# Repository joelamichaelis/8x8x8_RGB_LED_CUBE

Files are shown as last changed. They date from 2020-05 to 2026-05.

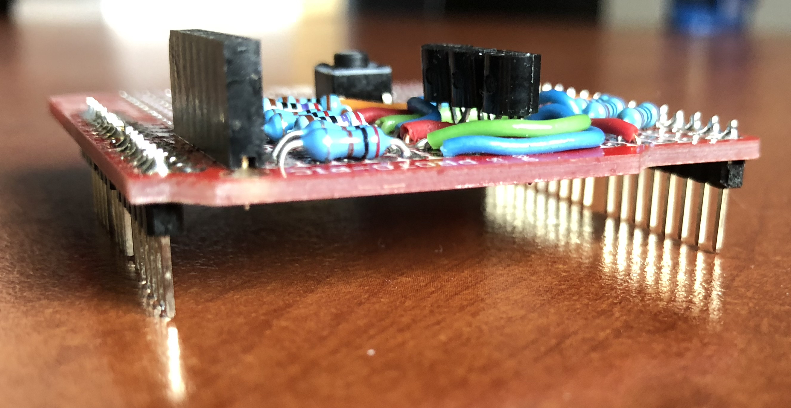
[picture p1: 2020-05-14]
Documents/Steve Manley Resources/Images/LED Tester.jpg

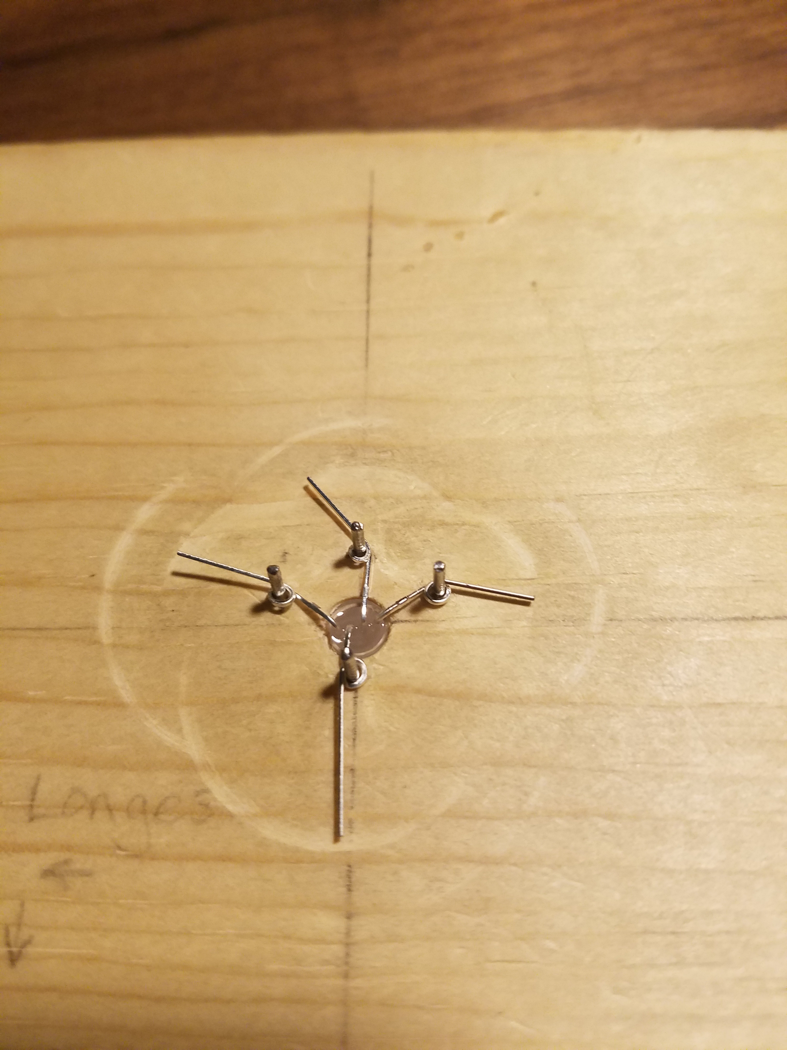
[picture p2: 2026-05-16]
Project Photos/Phase 1 Cube Build/01 LED Bending/20180319_184943.jpg

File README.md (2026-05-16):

#8x8x8 RGB LED Cube Project
2026: cleaning up the repo a bit and making public primarily for archival purposes.
This repo contains detail on the 8x8x8 RGB LED cube project I worked on in 2 phases between 2018 & 2021 primarily.

#Phase 1:
A classmate and I built the cube back in 2018 for our senior design class.
This encompassed:
1. building the physical cube itself.
2. building prototype grade electronics wired to the cube and arduino.
3. Programming the arduino to do basic animations on the cube.
This is all we had time to do.

#Pase 2:
I kept the RGB cube and after graduating wanted to keep working on the project.
I designed, ordered, and built a motherboard pcb which eliminates the need for a messy jumble of wires under the led cube and instead plugs in directly.
It is powered by a 5V 5-10A power supply, drives the LED cube with a STM32F103 Blue Pill, has a display LCD, capacitive touch menu naviagation system, and more.

#Current State:
I took an indefinite hiatus just short of having something visually impressive I can easily power on and showcase different animations on.
Designing the motherboard specifically was a great learning experience. This is the first serious PCBA schematic + layout I designed myself.
Same goes for the STM32 firmware piece. Prior to this I was still using primarily arduino.
If I were to continue the project in the future, I would prioritize first cleaning up the firmware repo because it is a mess.

Also, check out companion repo: https://github.com/joelamichaelis/Eight-Cubed-RGB.
It appears that I later made that repo to try and migrate away from the messy firmware files here. Not sure how well that helped now having 2 repos.

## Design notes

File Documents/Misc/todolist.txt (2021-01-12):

---------------------HW Considerations------------------------------------------------------

Drill holes in DC barrel jack footprint so it locks in place
Reconsider via spacings with consideration for CAF
Expandable modular GPIO interface feasibility
Is some sort of ext flash necessary?
Consider possibility of power switches for VLCD, ...

---------------------FW chicken scratching----------------------------------------------------

// the mask & color ar
fade (in or out?)
dissolve (in or out?) (ascending, descending, random?)
fade(dissolve) //

void raindrops (int initialFillDensity)
initial frame: The topmost layer frame is initialized to a certain "fill density"
subsequent frames: 
- shift down any active column by one
- count how many columns vanished. that's how many random columns to init next frame.

transition_punch	// already implemented 
transition_fade		// already implemented but need to clean up
transition_dissolve	// yet to be implemented. A combination of punch & fade

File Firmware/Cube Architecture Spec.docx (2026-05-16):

2026 note: don’t take this as source of truth. Looks like I was brainstorming stuff here. Some of this is true though.

Operational Modes:

- Video Mode
  - Cube runs through pre-scripted pattern sequences
- Interactive Mode
  - Cube takes inputs from peripherals to generate patterns
- Debug Mode
  - Allows user to toggle LEDs on and off manually for HW testing

Abstraction Layers:

Highest Level: Applicatation

Mid level:

- Controls the HW stuff
- LED mapping

Lowest Level:

Board config/initialization stuff

Application Layer

- Sequencer Layer slices 3d images into layers and sequences them
  - Layer Layer TLC set, clear, SPI convert, …
    - Chip Support Layer Board config stuff

Main.c:

- menu_system.c
  - mpr121.c
  - lcd_20x4_i2c.c
- animations.c
  - tlc5940.c
  - bool_mask.c
  - frame.c
  - lyr_frame.c

menu_system.c

Purpose:

synchronizes capacitive touch mpr121 inputs with the lcd to create a “menu system”

includes:

mpr121.c

lcd20x4_i2c.c

functions:

Purpose

char Menu_Read_Keypad();

char Menu_Read_Wheel();

Menu_TypeDef Menu_Scroll_Up(Menu_TypeDef tempMenu);

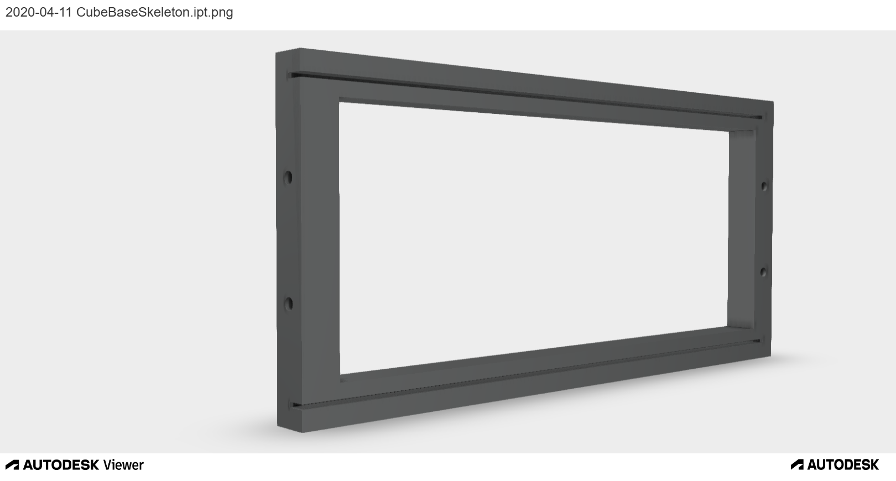
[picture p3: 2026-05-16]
Project Photos/Phase 2 Photos/Mechanical Renders/2020-04-11 CubeBaseSkeleton.ipt_REAR.png

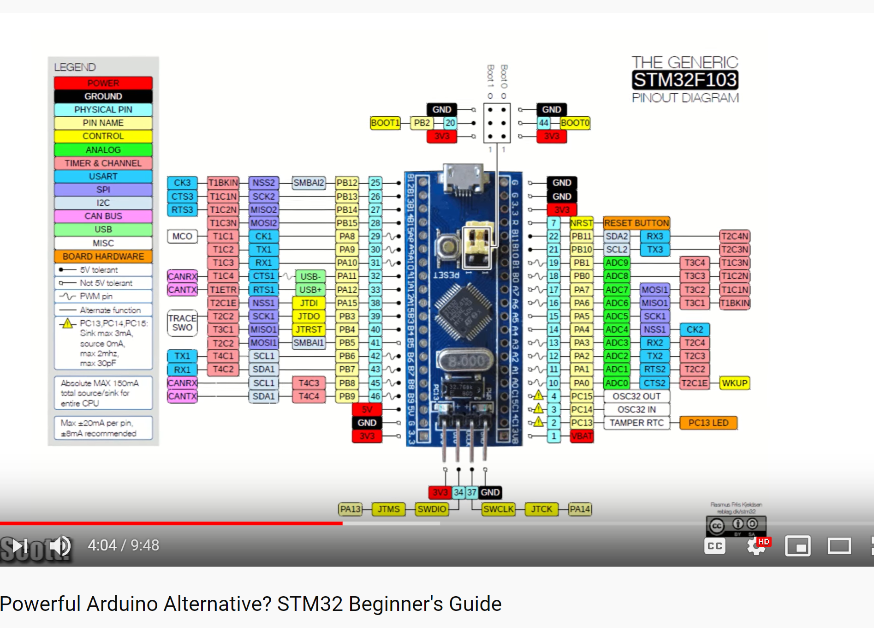
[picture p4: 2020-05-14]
Datasheets/Microprocessor/STM32F103 Generic Pinout.PNG

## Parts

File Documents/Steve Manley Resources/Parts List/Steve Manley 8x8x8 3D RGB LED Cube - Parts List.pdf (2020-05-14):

# Steve%Manley%– 8x8x8%3D%RGB%LED%Cube%– Parts%List

Item | Description | Quantity / Cube | Cost | Where Purchased | Additional Information
RGB LED | 5mm Diffused Common Anode RGB LED | 512 | £34.46 / 1000 LEDs | eBay: http://www.ebay.co.uk/itm/1000pcs-5mm-Round-top-Diffused-Multicolor-4-pins-Common-Anode-RGB-LED-light-/151281086209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: GB:1123
| Forward Voltage(V) If=20mA | Dominant wavelength(mm)K If=20mA | LuMen(LM) If=20mA | Reverse current(uA) Vr=5V | Power Angle (deg)
Min | Typ | Min | Typ | Min | Typ | Max
Red | 2.1 | 2.4 | 620 | 630 | 3000 | 4000 | 10 | 20-25
Green | 3.0 | 3.4 | 520 | 530 | 6000 | 8000 | 10 | 20-25
Blue | 3.0 | 3.4 | 460 | 465 | 4000 | 5000 | 10 | 20-25
Tinned Copper Wire | 20 SWG (or 20 AWG) 500g Real | 1 | £13.55 / Real | eBay: http://www.ebay.co.uk/itm/20-SWG-Tinned-Copper-Wire-500g-CB903-/160533739486?ssPageName=ADME:L:OU: GB:3160
Parameter | Value
Conductor Area CSA | 0.66mm²
External Diameter | 0.914mm
Conductor Make-up | 1/0.914mm
Current Rating | 33A
SWG Number | 20
Length | 86m
Base PCB | Interface for the Cube and Control Circuits Custom sized board with white solder mask. | 1 | £276 / 5 Boards | Proto-Pic: http://proto-pic.co.uk/large-pcb-prototype-manufacturing-service-250mm-x-250mm/ | Board Dimension are: 100mm x 100mm (max) for standard PCB (quantity 10) 250mm x 250mm (max) for larger PCB (quantity 5)
Parameter | Value
Material | FR-4
Board Dimension (min) | 10mm X10mm
Outline Dimension Accuracy | ± 0.2mm
Board Thickness | 1.6mm
Board Thickness Tolerance | ± 10%
Dielectric Separation thickness | 0.075mm--5.00mm
Conductor Width (min) | 0.15mm( Recommend>8mil )
Conductor Space (min) | 0.15mm( Recommend>8mil)
Outer Conductor thickness | 35um (1 Oz Copper)
Inner Conductor thickness | 17um--100um
Copper to Edge | 0.25mm,0.5mm
Plated Component,Plated via Diameter(Mechanical) | 0.3mm--6.30mm
Plated Hole Diameter Tolerance(Mechanical) | 0.08mm
Unplated Hole Diameter Tolerance | 0.05mm
Hole Space(min) | 0.25mm
Hole to Edge | 0.4mm
Annular Ring(min) | 0.15mm
Aspect Ratio | 8:01
Solder Resist Type | Photosensitive ink
Solder Resist Color | Black ,Green, White, Blue ,Yellow, Red
Solder Resist Clearance | 0.1mm
Solder Resist Coverage | 0.1mm
Plug Hole Diameter | 0.3mm--0.65mm
Selective Finish | HASL, ENIG
Silkscreen line width (mim) | 6mil
8 Pin Male SM Header | 8 Pin Mail surface Mount Header (mounts onto Base PCB) | 24 | £0.29 each | Proto-Pic: http://proto-pic.co.uk/header-8-pin-male-smd-0-1/ | Pin spacing is 0.1 inch See Datasheet on vendor website
8 Pin Female Header | 8 Pin Female Stackable Header (mounts onto Shift Register Boards) | 24 | £0.35 each | Proto-Pic: http://proto-pic.co.uk/8-pin-stackable-header-for-arduino/ | Pin spacing is 0.1 inch See Datasheet on vendor website
4 Way Molex Housing | Molex 22-01-2045 Crimp Housing, 2.54MM, 4 way | 17 | £2.10 / pack 10 | Farnell: http://uk.farnell.com/molex/22-01-2045/crimp-housing-2-54mm-4way/dp/143128?CMP=i-bf9f-00001000 | Pin spacing is 0.1 inch See Datasheet on vendor website
4 Pin Molex Header | Molex 22-05-7048 Connector, Header, THT, RA, 2.54MM, 4 way | 17 | £2.84 / pack 5 | Farnell: http://uk.farnell.com/molex/22-05-7048/connector-header-tht-ra-2-54mm/dp/9731628?ost=9731628 | Pin spacing is 0.1 inch See Datasheet on vendor website
Shift Register Board | Drives the LED Cathodes

## Standard sized board

## 4 £78 / 10 Boards

## Proto-Pic:

https://proto-pic.co.uk/pcb-prototypemanufacturing-service-10-boards/

Anode Driver Board | Multiplexes the Anodes

## Custom sized board

## 1 £100 / 5 Boards

## Proto-Pic:

http://proto-pic.co.uk/large-pcb-prototypemanufacturing-service-250mm-x-250mm/

Item | Description | Quantity / Cube | Cost | Where Purchased | Additional Information
Molex Contact Pin | Molex 08-50-0032 Contact, Socket, 30-22AWG, Crimp | 60 | £7.38 / pack 100 | Farnell: http://uk.farnell.com/molex/08-50-0032/contact-socket-30-22awg-crimp/dp/2424111?MER=baynote-2424111-pr | See Datasheet on vendor website
Pluggable Terminal Block 3 Way 5MM | Imo Precision Controls 20.130M/3 Terminal Block, Pluggable, 3POS, 5MM,14AWG | 5 | £1.42 / pack 2 | Farnell: http://uk.farnell.com/imo-precision-controls/20-130m-3/terminal-block-pluggable-3pos/dp/9632590 | See Datasheet on vendor website
Header Through Hole 5MM | Imo Precision Controls 20.130M/PS Connector, Header, THT, 5MM, 24WAY | 15 | £1.09 / strip 24 | Farnell: http://uk.farnell.com/imo-precision-controls/20-130m-ps/connector-header-tht-5mm-24way/dp/9632620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 | See Datasheet on vendor website
Shift Register TLC5916IN | Texas Instruments TLC5916IN Constant Current, LED Driver, 8Bit, PDIP16 | 24 | £1.53 each | Farnell: http://uk.farnell.com/texas-instruments/tlc5916in/ic-led-driver-8ch-pdip16/dp/1647814?CMP=i-bf9f-00001000 | See Full Datasheet on vendor website
Shift Register SN74HC595N | Texas Instruments SN74HC595N Shift Register, 8BIT, DIP16 | 1 | £0.54 each | Farnell: http://uk.farnell.com/texas-instruments/sn74hc595n/shift-register-8bit-74hc595-dip16/dp/9591664 | See Full Datasheet on vendor website
Hex Buffer | Texas Instruments CD74HC4050E Logic, Non-inverting, Hex, 1 Input, 16DIP | 1 | £0.48 each | Farnell: http://uk.farnell.com/texas-instruments/cd74hc4050e/logic-non-inv-hex-1input-16dip/dp/1739945?ost=1739945 | See Full Datasheet on vendor website
P-Channel Power MOSFET 19A | International Semiconductors AUIRF9Z34N MOSFET, P CH, 55V, 19A, TO-220AB | 8 | £0.94 each | Farnell: http://uk.farnell.com/international-rectifier/auirf9z34n/mosfet-p-ch-55v-19a-to-220ab/dp/2062068?ost=2062068 | See Full Datasheet on vendor website
Rectifier Diode 1A | Vishay General Semiconductor 1N4004 E3/54 Rectifier, Standard, 1A, 400V, DO-204AL | 1 | £0.95 each | Farnell: http://uk.farnell.com/vishay-general-semiconductor/1n4004-e3-54/rectifier-standard-1a-400v-do/dp/2335181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 | See Datasheet on vendor website
Capacitor 100nF 50V | Kemet C320C104K5R5TA CAP, MLCC, X7R, 100NF, 50V, RAD | 34 | £1.02 / pack 10 | Farnell: http://uk.farnell.com/kemet/c320c104k5r5ta/ca p-mlcc-x7r-100nf-50v-rad/dp/1457655?ost=1457655 | See Datasheet on vendor website

Item | Description | Quantity / Cube | Cost | Where Purchased | Additional Information
Capacitor 100uF 25V Electrolytic | Rubycon 25YXF100MEFC6.3X11 CAP, ALU ELEC, 100UF, 25V, RAD | 6 | £0.79 / pack 5 | Farnell: http://uk.farnell.com/rubycon/25yxf100mefc6-3x11/cap-alu-elec-100uf-25v-rad/dp/1144620?ost=1144620 | See Datasheet on vendor website
Resistor 100R 0.25W | Multicomp MF25 100R Resistor, 0.25W, 1% | 8 | £1.35 / pack 50 | Farnell: http://uk.farnell.com/multicomp/mf25-100r/resistor-100r-0-25w-1/dp/9341099?ost=9341099 | See Datasheet on vendor website
Resistor 100R 0.25W | Multicomp MF12 1K Resistor, 0.125W, 1% | 32 | £0.29 / pack 10 | Farnell: http://uk.farnell.com/multicomp/mf12-1k/resistor-1k-0-125w-1/dp/9342400 | See Datasheet on vendor website
6V 3.3A Power Supply | Ideal Power Supply 6V 5206-20S06-V-3A PSU, 6V, 3.3A, Earthed Output | 1 | £15.78 each | Farnell: http://uk.farnell.com/ideal-power/5206-20s06-v-3a/psu-6v-3-3a-earthed-output/dp/2112015?ost=2112015 | See Datasheet on vendor website

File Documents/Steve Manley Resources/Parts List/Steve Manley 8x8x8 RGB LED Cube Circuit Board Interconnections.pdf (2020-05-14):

Steve Manley 8x8x8 RGB LED Cube - Circuit Board Interconnections

Anode Driver Board | Arduino Uno
JP1 - DATA IN | Pin 11
JP1 - CLK IN | Pin 13
JP1 - LE IN | Pin 3
JP1 - ~OE IN | Pin 2
JP2 - GND | GND (next to Pin 13)
X4 - 6V IN | DC Power Jack +V
X5 - GND | DC Power Jack 0V
Anode Driver Board JP3 | Shift Register Board 1 JP1
Pin 1 | Pin 1
Pin 2 | Pin 2
Pin 3 | Pin 3
Pin 4 | Pin 4
Anode Driver Board JP4 | Shift Register Board 1 JP2
GND | Pin 4
Anode Driver Board JP5 | Shift Register Board 3 JP1
Pin 2 | Pin 2
Pin 3 | Pin 3
Pin 4 | Pin 4
Anode Driver Board | Base Board
X1 – A0 | Anode 0
X1 – A1 | Anode 1
X1 – A2 | Anode 2
X2 – A3 | Anode 3
X2 – A4 | Anode 4
X3 – A5 | Anode 5
X3 – A6 | Anode 6
X3 – A7 | Anode 7
Anode Driver Board | External 6V Power Supply
X4 - 6V IN | +6 Volts
X5 - GND | 0 Volts

Shift Register Board 1 JP3 | Shift Register Board 2 JP1
Pin 1 | Pin 1
Pin 2 | Pin 2
Pin 3 | Pin 3
Pin 4 | Pin 4
Shift Register Board 2 JP3 | Shift Register Board 3 JP1
Pin 1 | Pin 1
Shift Register Board 3 JP3 | Shift Register Board 4 JP1
Pin 1 | Pin 1
Pin 2 | Pin 2
Pin 3 | Pin 3
Pin 4 | Pin 4

Shift Register Board 4 JP3
Pin 1 – Not Connected
Pin 2 – Not Connected
Pin 3 – Not Connected
Pin 4 – Not Connected
All Shift Register Boards JP2 | Anode Driver Board
Pin 1 – Not Connected
Pin 2 | X4 - 5V OUT
Pin 3 | X5 - GND

All Shift Register Boards JP2
Board 1 Pin 4 | Board 2 Pin 4
Board 2 Pin 4 | Board 3 Pin 4
Board 3 Pin 4 | Board 4 Pin 4

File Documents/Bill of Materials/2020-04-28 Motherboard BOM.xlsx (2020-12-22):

 |  | Distributor | In Stock? | QTY | Unit Cost ($) | Extended Cost ($) | URL
 | BC847CW,115 | LCSC | Y | 15 | 0.02 | 0.3 | https://lcsc.com/product-detail/Transistors-NPN-PNP_Nexperia-BC847CW-115_C75567.html | Q3, Q4, Q7, Q8, Q11, Q12, Q15, Q16, Q18, Q21, Q22, Q25, Q26, Q29, Q30
 | BC857 | LCSC | Y | 7 | 0.013017 | 0.091119 | https://lcsc.com/product-detail/Transistors-NPN-PNP_ST-Semtech-BC857_C148244.html | Q17, Q19, Q20, Q23, Q24, Q27, Q28
 | BSS138LT1G | Digikey | Y | 2 | 0.25 | 0.5 | https://www.digikey.com/product-detail/en/on-semiconductor/BSS138LT1G/BSS138LT1GOSCT-ND/917858 | Q31, Q32
 | IRF9540 | Digikey | Y | 8 | 2.32 | 18.56 | https://www.digikey.com/product-detail/en/vishay-siliconix/IRF9540STRLPBF/IRF9540STRLPBFCT-ND/3305342 | Q1, Q2, Q5, Q6, Q9, Q10, Q13, Q14
 | LED-0603-001 | LCSC | Y | 2 | 0.066219 | 0.132438 | https://lcsc.com/product-detail/Infrared-IR-LEDs_IR19-21C-TR8-AQL_C142316.html | DS1, DS2
 | RES-0402-75K | LCSC | Y | 2 | 0.000904 | 0.001808 | https://lcsc.com/product-detail/Chip-Resistor-Surface-Mount_UNI-ROYAL-Uniroyal-Elec-0402WGF7502TCE_C25798.html | R86, R89
 | RES-0402-10K | LCSC | Y | 4 | 0.000981 | 0.003924 | https://lcsc.com/product-detail/Chip-Resistor-Surface-Mount_10KR-1002-1_C60490.html | R80, R81, R82, R83
 | RES-0402-100K | LCSC | Y | 2 | 0.004303 | 0.008606 | https://lcsc.com/product-detail/Chip-Resistor-Surface-Mount_Walsin-Tech-Corp-WF04H1003DTL_C305256.html | R85, R88
 | RES-0603-0202 | LCSC | Y | 12 | 0.002233 | 0.026796 | https://lcsc.com/product-detail/Chip-Resistor-Surface-Mount_2KR-2001-1_C105576.html | R66-R77
 | RES-0603-0392 | LCSC | Y | 7 | 0.002348 | 0.016436 | https://lcsc.com/product-detail/Chip-Resistor-Surface-Mount_3-9KR-3901-1_C114616.html | R30, R35, R36, R46, R47, R56, R57
 | RES-0603-0103 | LCSC | Y | 39 | 0.002023 | 0.078897 | https://lcsc.com/product-detail/Chip-Resistor-Surface-Mount_10KR-103-5_C99198.html | R1, R2, R3, R4, R5, R6, R9, R10, R11, R12, R14, R15, R17, R18, R20, R21, R22, R23, R24, R25, R26, R27, R28, R29, R31, R33, R37, R38, R41, R42, R48, R49, R52, R53, R58, R59, R62, R63, R78
 | RES-0603-0123 | LCSC | Y | 7 | 0.002779 | 0.019453 | https://lcsc.com/product-detail/Chip-Resistor-Surface-Mount_12KR-1202-1_C114659.html | R34, R43, R44, R54, R55, R64, R65
 | RES-0603-0153 | LCSC | Y | 7 | 0.00247 | 0.01729 | https://lcsc.com/product-detail/Chip-Resistor-Surface-Mount_15KR-1502-1_C114661.html | R32, R39, R40, R50, R51, R60, R61
 | RES-0603-0203 | LCSC | Y | 1 | 0.002348 | 0.002348 | https://lcsc.com/product-detail/Chip-Resistor-Surface-Mount_20KR-203-5_C22173.html | R79
 | RES-0603-0R0 | LCSC | Y | 5 | 0.00188 | 0.0094 | https://lcsc.com/product-detail/Chip-Resistor-Surface-Mount_0R-0R-5_C95177.html | R7, R8, R13, R16, R45
 | RES-0603-2673 | LCSC | Y | 1 | 0.003186 | 0.003186 | https://lcsc.com/product-detail/Chip-Resistor-Surface-Mount_267KR-2673-1_C185347.html | R19
 | CAP-0603-0105 | LCSC | Y | 16 | 0.022258 | 0.356128 | https://lcsc.com/product-detail/Others_Murata-Electronics_GCJ188R71H104KA12D_Murata-Electronics-GCJ188R71H104KA12D_C161115.html | C7-C18, C19, C20, C21, C22
 | MIC5225-3.3YM5 |  |  | 1 |  | 0 |  | U1
 | TPS62840DLC | Digikey | Y | 1 | 1.83 | 1.83 |  | U2
 | ICS-5940-001 | Digikey | Y | 12 | 2.79 | 33.48 | https://www.digikey.com/product-detail/en/texas-instruments/TLC5940PWPR/296-35975-1-ND/4135049 | U3-U14
 | ICS-MPR121-QR2 | LCSC | Y | 2 | 1.054773 | 2.109546 | https://lcsc.com/product-detail/Touch-Screen-Controller-ICs_NXP-Semicon_MPR121QR2_NXP-Semicon-MPR121QR2_C91322.html | U15, U16
 | IND-1812-2R2 | LCSC | N | 1 | 0.141018 | 0.141018 | https://lcsc.com/product-detail/Inductors-SMD_TDK-NLC453232T-2R2K-PF_C307780.html | L1
 | MSE-0001-001 | LCSC | Y | 1 | 0.065 | 0.065 | https://lcsc.com/product-detail/Surface-Mount-Fuses_AEM_F1206VH8000TM_AEM-F1206VH8000TM_C310984.html | F1
 | HEADER-01x12 | LCSC | Y | 2 | 0.191434 | 0.382868 | https://lcsc.com/product-detail/Pin-Header-Female-Header_CJT-Changjiang-Connectors-A2541WV-12P_C225487.html | H5, H7
 | HEADER-01x20 | LCSC | Y | 2 | 0.10633 | 0.21266 | https://lcsc.com/product-detail/Pin-Header-Female-Header_BOOMELE-Boom-Precision-Elec-C50984_C50984.html | H1, H2
 | HEADER-01X08 | LCSC | Y | 24 | 0.051646 | 1.239504 | https://lcsc.com/product-detail/Pin-Header-Female-Header_BOOMELE-Boom-Precision-Elec-C27438_C27438.html | P1A-P12B
 | HEADER-01x06 | LCSC | Y | 2 | 0.020051 | 0.040102 | https://lcsc.com/product-detail/Pin-Header-Female-Header_BOOMELE-Boom-Precision-Elec-C37208_C37208.html | H6, H8
 | HEADER-01x04 | LCSC | Y | 1 | 0.076156 | 0.076156 | https://lcsc.com/product-detail/Pin-Header-Female-Header_CJT-Changjiang-Connectors-A2541HWV-4P_C225501.html | H3
 | HEADER-02X04 | LCSC | Y | 1 | 0.095414 | 0.095414 | https://lcsc.com/product-detail/Pin-Header-Female-Header_Ckmtw-Shenzhen-Cankemeng-C124422_C124422.html | H4
 | CON-0001-001 | Digikey | Y | 1 | 0.75 | 0.75 | https://www.digikey.com/product-detail/en/tensility-international-corp/54-00164/839-54-00164CT-ND/10459311 | P1
 | CON-0001-002 | Digikey | Y | 1 | 1.05 | 1.05 | https://www.digikey.com/product-detail/en/gct/DCJ200-05-A-K1-A/2073-DCJ200-05-A-K1-ACT-ND/9859678 | P1
backup | MIC5219-3.3YM5TR |  |  |  |  |  | https://lcsc.com/product-detail/Low-Dropout-Regulators-LDO_MICROCHIP_MIC5219-3-3YM5_MIC5219-3-3YM5_C29613.html
 | solder paste
 | LEDs
 | bus wire

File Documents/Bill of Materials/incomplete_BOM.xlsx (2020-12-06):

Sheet: Sheet1
Item |  | Price ($) |  | Current Rating (A) | Voltage Rating (V) | Distributor PN
DC Barrel Jack |  | 0.75 |  | 5.5 | 48 |  |  | https://www.digikey.com/product-detail/en/tensility-international-corp/54-00164/839-54-00164CT-ND/10459311
DC Barrel Jack |  | 1.05 |  | 5 | 20 |  |  | https://www.digikey.com/product-detail/en/gct/DCJ200-05-A-K1-A/2073-DCJ200-05-A-K1-ACT-ND/9859678
DC PSU |  |  |  | 6 | 6 |  |  | https://www.amazon.com/Switch-solutions-100V-240V-adapter-5-5X2-5mm/dp/B079CFPRP3
Fuse |  |  |  |  |  | C310984 | 1206, 7mOhm, 8A, Medium/Regular Blow | https://lcsc.com/product-detail/Surface-Mount-Fuses_AEM_F1206VH8000TM_AEM-F1206VH8000TM_C310984.html
IRF9540 |  |  |  |  |  |  | TO263-2, Pchan, 4A Minimum Max current | https://lcsc.com/products/MOSFET_381.html
LCD | 20x4 I2c backpack | 3.99 | Banggood | Geekcreit® IIC I2C 2004 204 20 x 4 Character LCD Display Screen Module Blue Geekcreit for Arduino - products that work with official Arduino boards
cubeBasePCB |  | 4.00 | JLCPCB
Motherboard |  | 5.00 | JLCPCB
3d printed parts |  | 7.00 | prusament & electricity
capatouch pcb |  | 20.00 | DFRobot | outrageous
MPR121 PCB Pair |  | 6.99 | Amazon
DC PSU | 25W 5V 5A | 14.99 | Amazon
LEDs | Diffused Common Anode | 51.54 | Amazon | Chanzon 100 pcs 5mm RGB Multicolor Diffused LED Diode Lights Common Anode(Frosted Round Tricolor) 4 pin Bright Lighting Bulb Lamps Electronics Components Indicator Light Emitting Diodes
MCU | STM32F103C8T6 Microboard | 2.29 | Aliexpress | STM32F103C8T6 ARM STM32 Small System Development Board Module SCM Core Board

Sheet: Sheet2
Item | QTY | Total Cost | Item Cost ($) | Shipping ($) | Tax ($) | ETA
STLinkV2 | 10 | 33.69 | 23.50 | 7.88 | 2.31 | DEC 17th 2020 to Jan 06 2021
TLC5940 | 60 | 63.57 | 55.2 | 4.00 | 4.37 | DEC 17th 2020 to Jan 06 2021
STM32F103C8T6 | 10 | 28.99 | 14.5 | 12.5 | 1.99 | by Jan 8th?
LCDs | 10 | 48.64 | 42.3 | 3 | 3.34 | By Jan 15
MPR121 Breakout | 20 | 30.87 | 26 | 2.75 | 2.12 | By Feb 23!?
M4-0.7x20mm screw | 100 | 15.02 | 13.99 | 0 | 1.03 | 2020-12-08
M3-0.5x8mm | 100 | 7.41 | 6.9 | 0 | 0.51 | 2020-12-09
Grand Total |  | 228.19

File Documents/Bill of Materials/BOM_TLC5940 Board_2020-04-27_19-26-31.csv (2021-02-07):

ID | Name | Designator | Footprint | Quantity | Manufacturer Part | Manufacturer | Supplier | Supplier Part | LCSC Assembly
1 | 10uF | C3,C6 | CAP-SMD_L2.0-W1.2 | 2 | TAJR106M006RNJ | AVX | LCSC | C7235 | Yes
2 | IRF9540 | Q2,Q6,Q14,Q10,Q9,Q13,Q5,Q1 | TO-263-2_L10.0-W9.1-P5.08-LS15.2-BR | 8 | IRF9540NSTRLPBF | IR | LCSC | C33903 | Yes
3 | 0.1uF | C7,C8,C9,C10,C14,C13,C12,C11,C18,C17,C16,C15 | 0603 | 12 |  |  | LCSC | C161115
4 | 2K | R66,R67,R68,R69,R73,R72,R71,R70,R77,R76,R75,R74 | 0603-RES | 12 |  |  | LCSC | C192167
5 | 10K | R81,R80,R82,R83 | 0402 | 4 | 0402WGF1002TCE | UniOhm | LCSC | C25744 | Yes
6 | 10uF | C1,C2,C4,C5 | 0805 | 4 | CL21A106KAYNNNE | SAMSUNG | LCSC | C15850 | Yes
7 | 10K | R2,R6,R4,R12,R15,R10,R25,R29,R27,R21,R23,R18,R17,R22,R20,R26,R28,R24,R9,R3,R5,R1,R37,R41,R33,R31,R62,R52,R48,R49,R53,R63,R59,R42,R38 | 0603 | 35 |  |  | LCSC | C99198
8 | 10K | R14,R58 | 0603 | 2 | 0603WAD1002T5E | Uniroyal Elec | LCSC | C167144 | Yes
9 | 10K | R11 | 0603 | 1 |  |  | LCSC
10 | 10K | R78 | 0603 | 1 |  |  | LCSC | C99198 | Yes
11 | 20K | R79 | 0603 | 1 |  |  | LCSC | C278637 | Yes
12 | 12K | R43,R34,R64,R54,R55,R65,R44 | 0603 | 7 | 0603WAD1002T5E | Uniroyal Elec | LCSC | C167144 | Yes
13 | 15K | R39,R32,R60,R50,R51,R61,R40 | 0603 | 7 | 0603WAD1002T5E | Uniroyal Elec | LCSC | C167144 | Yes
14 | 3.9K | R35,R30,R56,R46,R47,R57,R36 | 0603 | 7 | 0603WAD1002T5E | Uniroyal Elec | LCSC | C167144 | Yes
15 | 100K | R88,R85 | 0402 | 2 | AC0402FR-07100KL | YAGEO | LCSC | C144809
16 | Header-Female-2.54_2x4 | H4 | HDR-TH_8P-P2.54-V-R2-C4-S2.54 | 1 | 220S-2*4P H=8.5MM Ytype Gold-plated | Ckmtw | LCSC | C124422
17 | Header-Male-2.54_1x6 | H8,H6 | HDR-TH_6P-P2.54-V | 2 | Header-Male-2.54_1x6 | BOOMELE | LCSC | C37208
18 | 267K | R19 | R0603 | 1 | ERJ3EKF2673V | PANASONIC | LCSC | C403117
19 | BC857 | Q19,Q17,Q27,Q23,Q24,Q28,Q20 | SOT-23-3_L2.9-W1.6-P1.90-LS2.8-BR | 7 | BC857 | SEMTECH | LCSC | C148244 | Yes
20 | 0.01 | R16,R7,R8,R13 | 0603 | 4 | 0603WAF100MT5E | Uniroyal Elec | LCSC | C270944 | Yes
21 | 0.01 | R45 | R0603 | 1 | 0603WAF100MT5E | Uniroyal Elec | LCSC | C270944 | Yes
22 | TPS62840DLC | U2 | WSON-8_L2.0-W1.5-P0.50 | 1
23 | 1K | R84,R87 | R0603 | 2 | MCT06030C1001FP500 | Vishay Intertech | LCSC | C161809
24 | 2.2uH | L1 | L1812 | 1 | NLC453232T-2R2K-PF | TDK | LCSC | C307780
25 | 75K | R89,R86 | 0402 | 2 | 0402WGF7502TCE | UniOhm | LCSC | C25798 | Yes
26 | TLC5940PWPR | U3,U4,U5,U6,U10,U9,U8,U7,U14,U13,U12,U11 | HTSSOP-28_29P-L9.80-W6.60-P0.65-BL-EP | 12 | TLC5940PWPR | TI | LCSC | C181653 | Yes
27 | A2541WV-12P | H5,H7 | HDR-TH_12P-P2.54-V_A2541HWV-12P | 2 | A2541WV-12P | Changjiang Connectors | LCSC | C225487
28 | Header-Female-2.54_1x8 | P1A,P1B,P2B,P2A,P3B,P3A,P4B,P4A,P8A,P8B,P7A,P7B,P6A,P6B,P5B,P5A,P12A,P12B,P11A,P11B,P10A,P10B,P9B,P9A | HDR-8X1/2.54 | 24 | Female headerHDR1X8-2.54 | BOOMELE | LCSC | C27438
29 | Header-Female-2.54_1x20 | H1,H2 | HDR-TH_20P-P2.54-V | 2 | 2.54mm 1*20P Female header | BOOMELE | LCSC | C50984
30 | 100nF | C21,C22,C20,C19 | 0603 | 4 | CT41-0603-2F4-50V-0.1uF-M(N) | TORCH | LCSC | C138344
31 | BSS138LT1G | Q31,Q32 | SOT-23-3_L2.9-W1.6-P1.90-LS2.8-BR | 2 | BSS138LT1G | ON | LCSC | C82045 | Yes
32 | MIC5225-3.3YM5 | U1 | SOT-23-5_L3.0-W1.7-P0.95-LS2.8-BL | 1 | MIC5225-3.3YM5-TR | Microchip Tech | Digi-Key | 576-2980-1-ND
33 | F1206VH8000TM | F1 | F1206 | 1 | F1206VH8000TM | AEM | LCSC | C310984
34 | BC847 | Q4,Q8,Q16,Q12,Q11,Q15,Q7,Q3,Q21,Q18,Q29,Q25,Q26,Q30,Q22 | SOT-323-3_L2.2-W1.3-P1.30-LS2.1-BL | 15 | BC847CW,115 | Nexperia | LCSC | C75567 | Yes
35 | 2.1MMJACKSMT | P1 | DCJACK_2MM_SMT | 1 |  |  | Digi-Key
36 | MPR121QR2 | U16,U15 | QFN-20_L3.0-W3.0-P0.40-BL | 2 | MPR121QR2 | NXP Semicon | LCSC | C91322 | Yes
37 | IR19-21C/TR8(AQL) | DS2,DS1 | LED-0603 | 2 | IR19-21C/TR8(AQL) | EVERLIGHT | LCSC | C142316 | Yes
38 | A2541HWV-4P | H3 | HDR-TH_4P-P2.54-V_A2541HWV-4P | 1 | A2541HWV-4P | Changjiang Connectors | LCSC | C225501

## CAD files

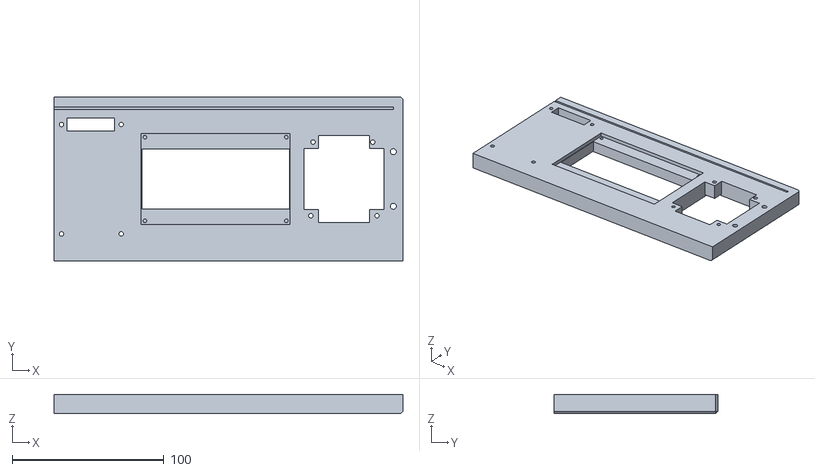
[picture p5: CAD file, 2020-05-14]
Mechanical/Inventor/2020-04-12 CubeBaseFull/2020-04-12 CubeBaseFull.obj
230.3 x 108.0 x 12.7

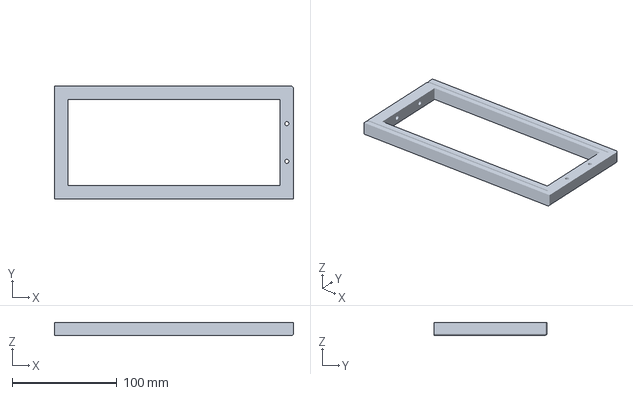
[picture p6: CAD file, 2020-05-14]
Mechanical/Inventor/2020-03-29 CubeBaseSkeleton/2020-03-29 CubeBaseSkeleton.3mf
228.6 x 107.9 x 12.7 mm

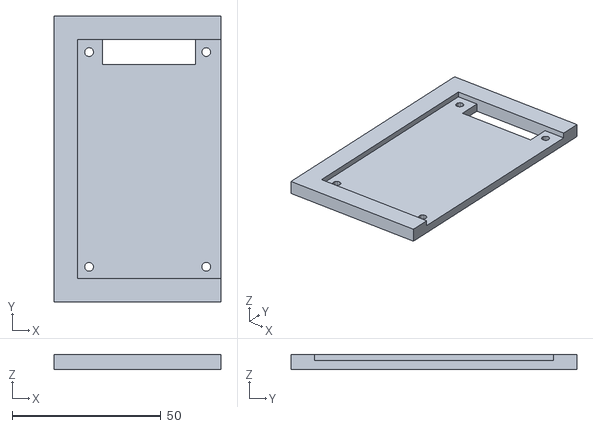
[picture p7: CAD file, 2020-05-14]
Mechanical/Inventor/KeypadOnly/2020-04-12 KeypadOnly.obj
56.2 x 96.0 x 5.00

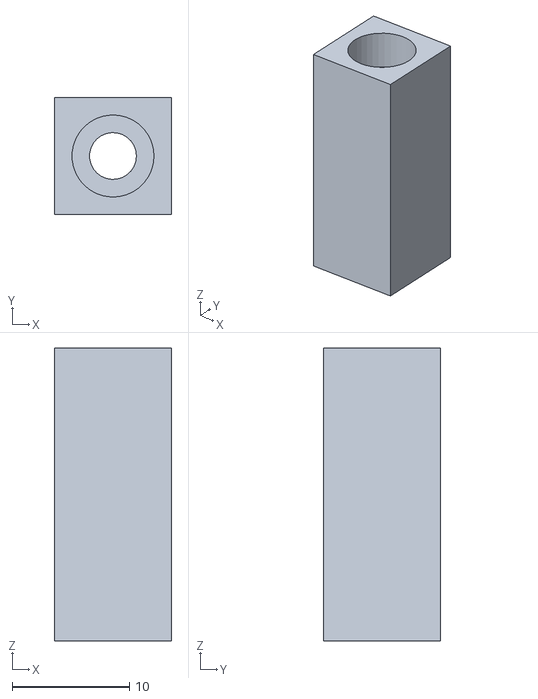
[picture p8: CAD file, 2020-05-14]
Mechanical/Inventor/Inventor Screw Hole Experimentation/m4x0.7 25mm long.obj
10.0 x 10.0 x 25.0

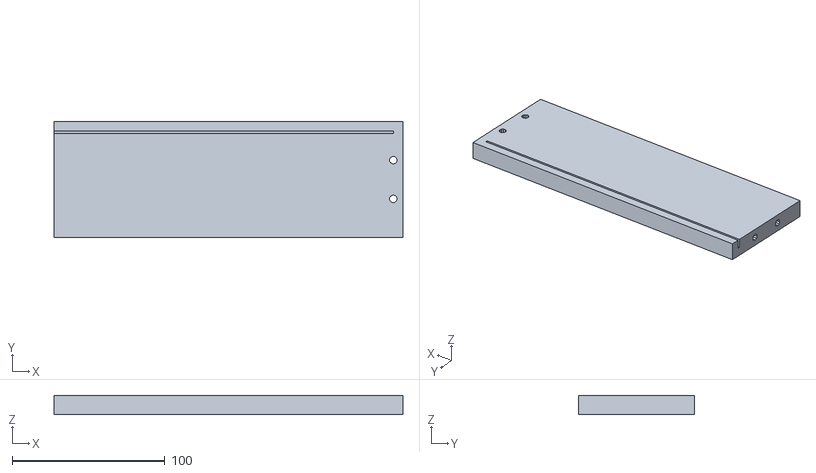
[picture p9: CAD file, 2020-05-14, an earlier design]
Mechanical/Inventor/Archive/2019-12-02 CubeBase_mm.obj
228.6 x 76.2 x 12.7

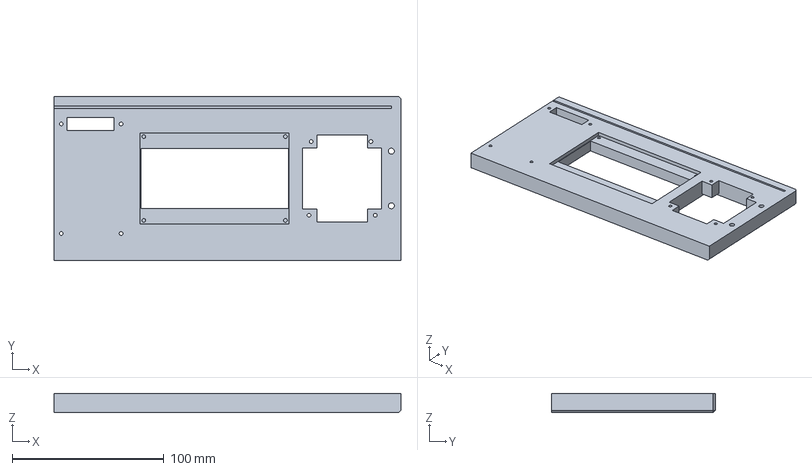
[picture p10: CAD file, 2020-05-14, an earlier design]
Mechanical/Inventor/Archive/2020-02-29 CubeBaseFront.3mf
228.6 x 108.0 x 12.7 mm

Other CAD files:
Mechanical/Inventor/2020-04-11 CubeBaseSkeleton/2020-04-11 CubeBaseSkeleton.3mf
Mechanical/Inventor/Archive/2020-02-23 CubeBaseFront.dwg
Mechanical/Inventor/Archive/2020-03-15 CubeBaseFront.obj
Mechanical/Inventor/1x8 SMD Header.ipt
Mechanical/Inventor/2020-03-29 CubeBaseFull.ipt
Mechanical/Inventor/2020-03-29 CubeBaseSkeleton/2020-03-29 CubeBaseSkeleton.ipt
Mechanical/Inventor/2020-03-29 CubeBaseSkeleton/2020-03-29 CubeBaseSkeleton.obj
Mechanical/Inventor/2020-04-11 CubeBaseSkeleton/2020-04-11 CubeBaseSkeleton.ipt
Mechanical/Inventor/2020-04-11 CubeBaseSkeleton/2020-04-11 CubeBaseSkeleton.obj
Mechanical/Inventor/2020-04-11 CubeBaseSkeleton/OldVersions/2020-04-11 CubeBaseSkeleton.0001.ipt
Mechanical/Inventor/2020-04-12 CubeBaseFull/2020-04-12 CubeBaseFull.ipt
Mechanical/Inventor/2020-04-12 CubeBaseFull/OldVersions/2020-04-12 CubeBaseFull.0004.ipt
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

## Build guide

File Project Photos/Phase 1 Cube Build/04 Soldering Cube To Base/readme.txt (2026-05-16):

I didn't take any photos during this stage, probably because I was too scared to mess up.
Panels get soldered vertically onto the base PCB referenced elsewhere. 
Each row's common power nodes are connected with a bus wire strip horizontally such that each 8x8 horizontal layer shares a common 8x8 grid power.

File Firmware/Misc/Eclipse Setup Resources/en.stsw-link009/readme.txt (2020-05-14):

Digitally signed USB driver for ST-Link/V2, ST-Link/V2-1 a	nd STLINK-V3 on Windows7, Windows8 and Windows10, 32 and 64 bits.

To install the driver, run stlink_winusb_install.bat in administrator mode, before connecting any ST-Link to the PC.

In case of issue, it's also possible to run (as administrator):
 - dpinst_x86.exe on 32 bits machines
 - dpinst_amd64.exe on 64 bits machines

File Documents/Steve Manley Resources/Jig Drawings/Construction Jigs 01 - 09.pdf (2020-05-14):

# 3D 8x8x8 RGB LED CUBE JIGS

# CREATED BY:

# DATE:

# REVISION:

# UPDATED:

JIG 01: LED LEAD FORMING JIG

JIG 02: ANODE RAIL FORMING JIG

JIG 03: ANODE RAIL EJECTOR

JIG 04: 8x8 PANEL FORMING JIG

JIG 05: HORIZONTAL ANODE LINK WIRE FORMING JIG

JIG 06: VERTICAL ANODE LINK WIRE FORMING JIG

JIG 07: CUBE CRADLE

JIG 08: 8x8 PANEL ALIGNMENT JIG

JIG 09: 8x8 PANEL HEIGHT SETTING JIG

# STEVE MANLEY

# 15th JULY 2014

2.0

# 26th DECEMBER 2014

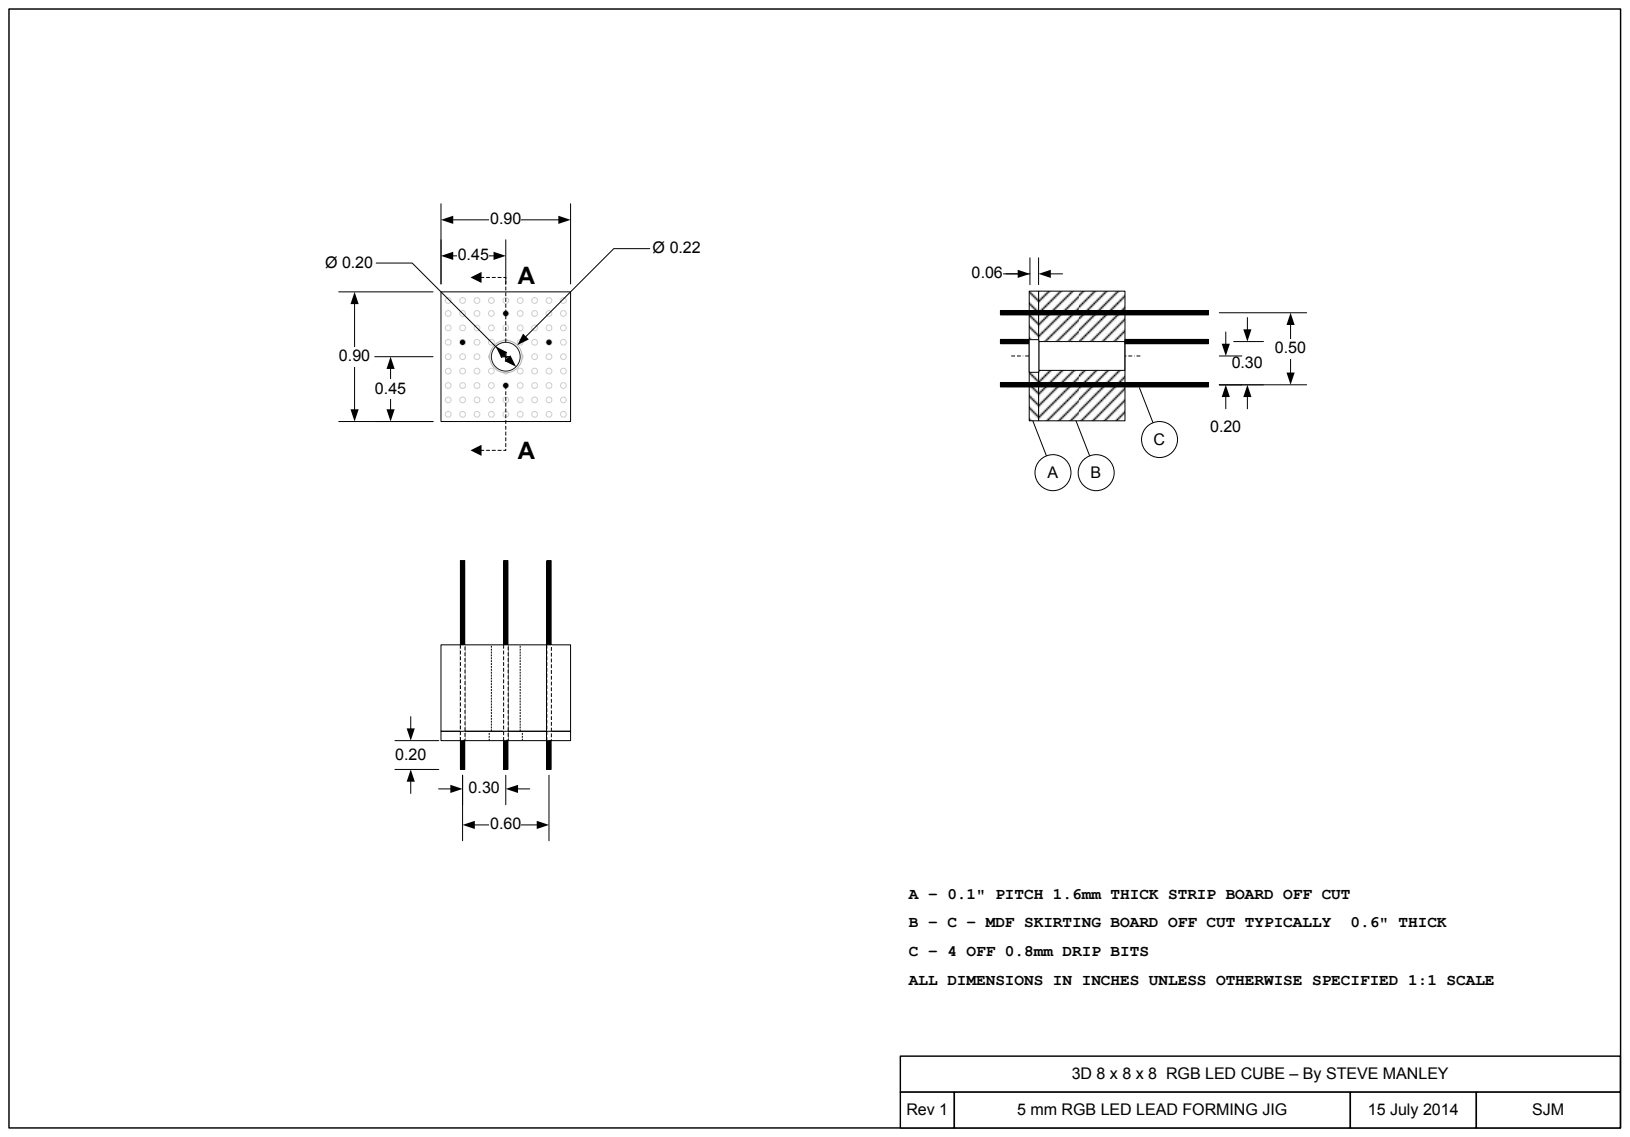
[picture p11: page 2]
Rev 1; 5 mm RGB LED LEAD FORMING JIG; 15 July 2014; SJM; B – C – MDF SKIRTING BOARD OFF CUT TYPICALLY; 0.6" THICK

A – 0.1" PITCH 1.6mm THICK STRIP BOARD OFF CUT

C – 4 OFF 0.8mm DRIP BITS

ALL DIMENSIONS IN INCHES UNLESS OTHERWISE SPECIFIED 1:1 SCALE

3D 8 x 8 x 8 RGB LED CUBE – By STEVE MANLEY

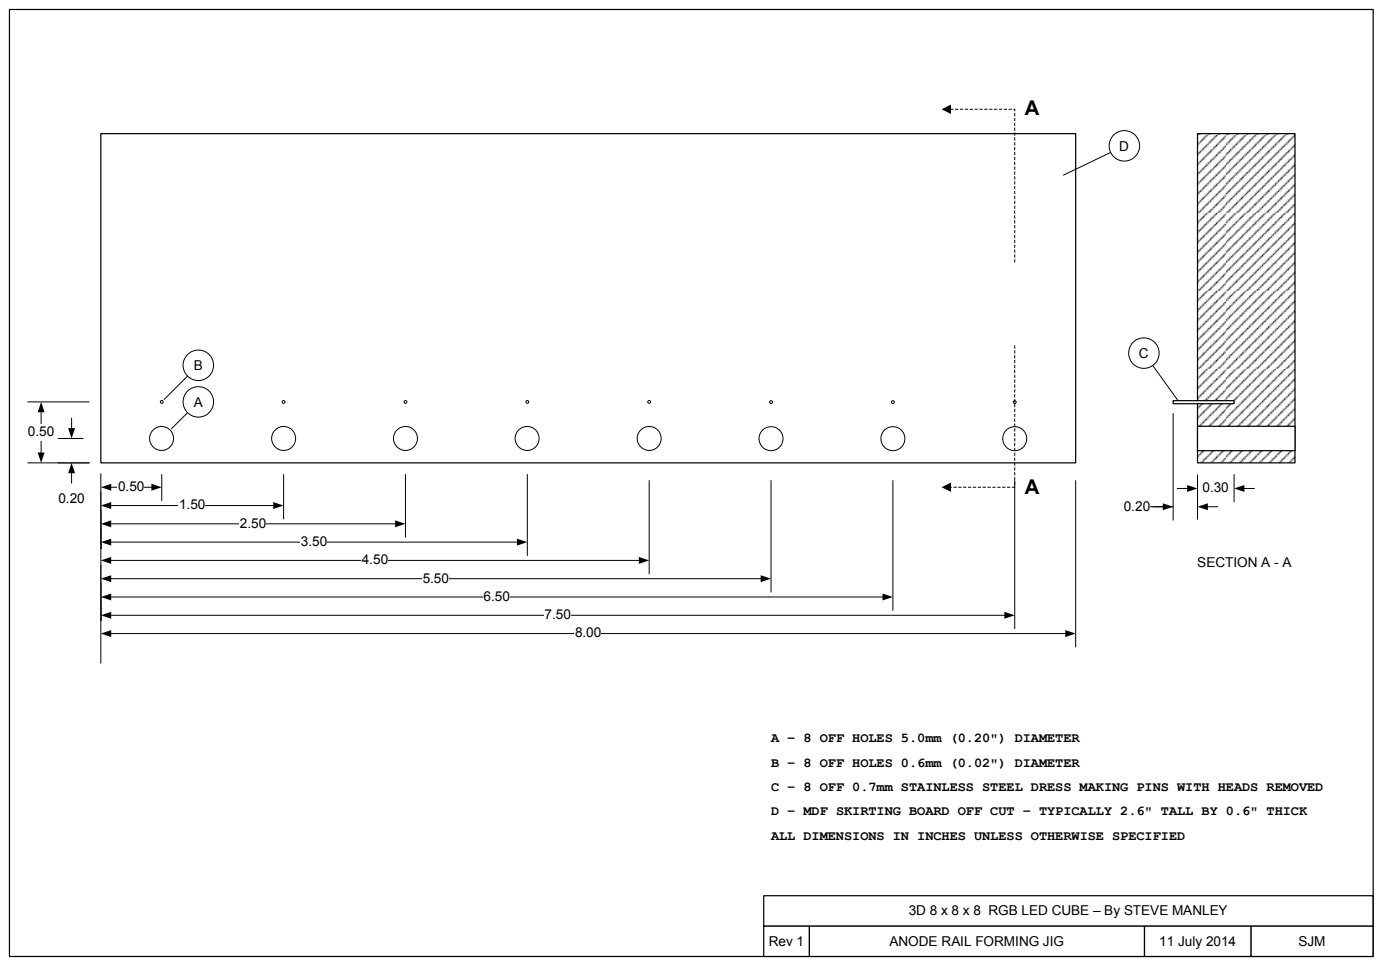
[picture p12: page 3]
Rev 1; ANODE RAIL FORMING JIG; 11 July 2014; SJM; SECTION A - A

A – 8 OFF HOLES 5.0mm (0.20") DIAMETER

B – 8 OFF HOLES 0.6mm (0.02") DIAMETER

C – 8 OFF 0.7mm STAINLESS STEEL DRESS MAKING PINS WITH HEADS REMOVED

D – MDF SKIRTING BOARD OFF CUT – TYPICALLY 2.6" TALL BY 0.6" THICK

ALL DIMENSIONS IN INCHES UNLESS OTHERWISE SPECIFIED

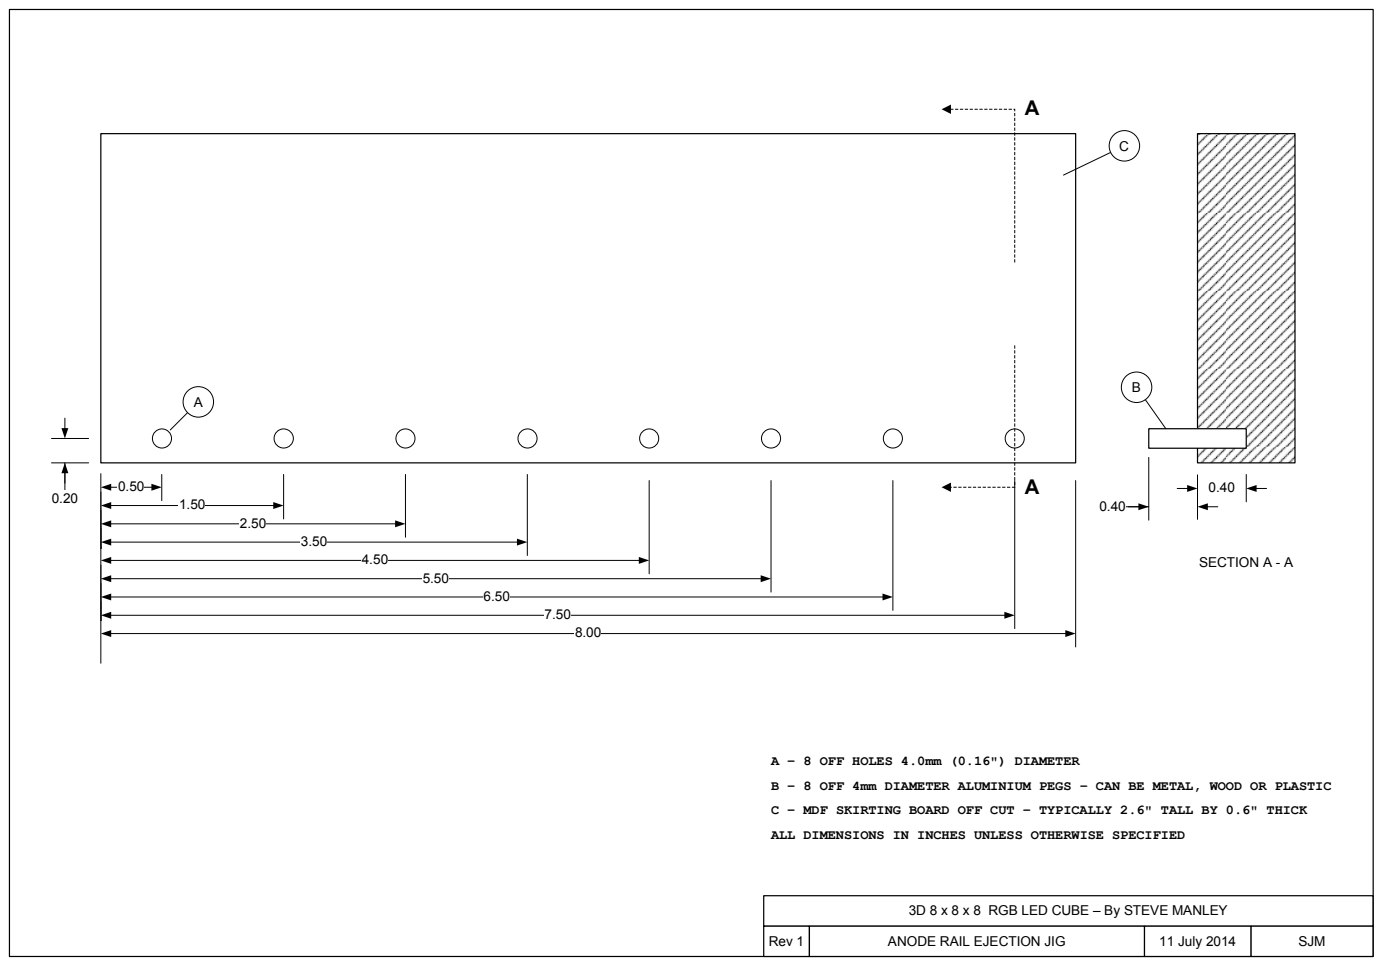
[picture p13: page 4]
Rev 1; ANODE RAIL EJECTION JIG; 11 July 2014; SJM; SECTION A - A

A – 8 OFF HOLES 4.0mm (0.16") DIAMETER

B – 8 OFF 4mm DIAMETER ALUMINIUM PEGS – CAN BE METAL, WOOD OR PLASTIC

C – MDF SKIRTING BOARD OFF CUT – TYPICALLY 2.6" TALL BY 0.6" THICK

ALL DIMENSIONS IN INCHES UNLESS OTHERWISE SPECIFIED

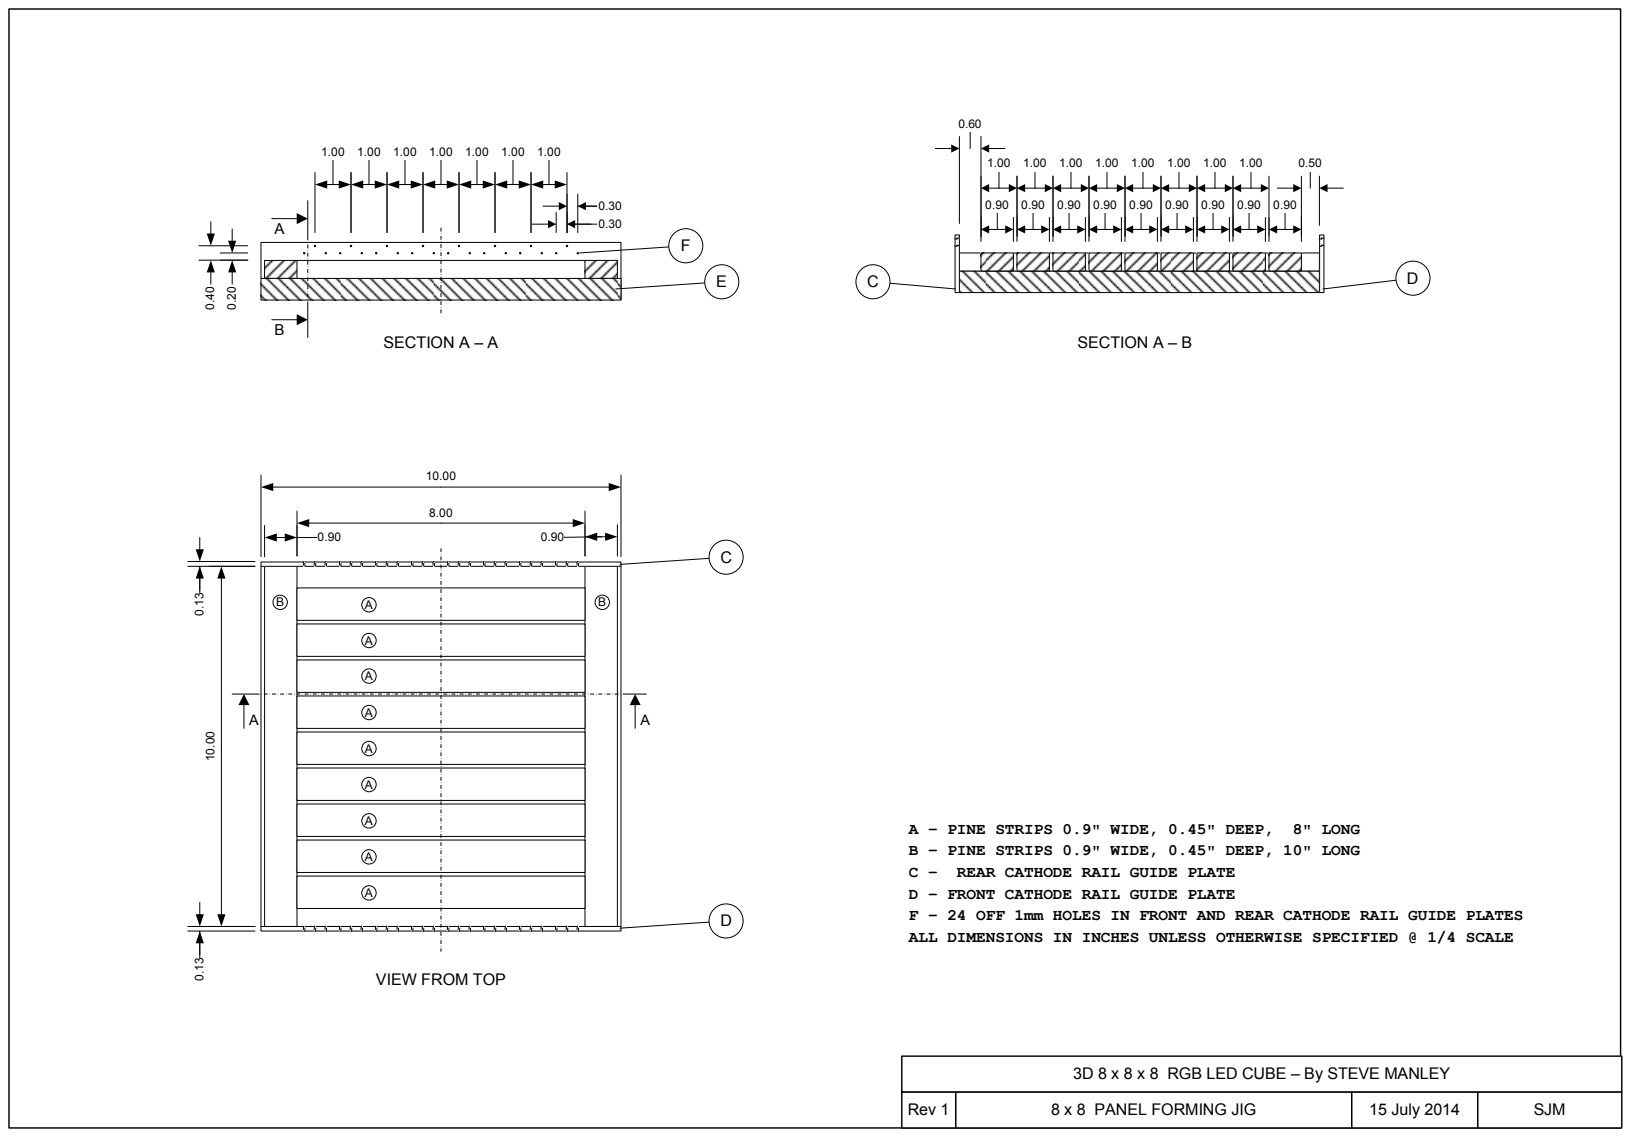
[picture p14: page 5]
Rev 1; 8 x 8 PANEL FORMING JIG; 15 July 2014; SJM; A – PINE STRIPS 0.9" WIDE, 0.45" DEEP,; 8" LONG; SECTION A – A; SECTION A – B; REAR CATHODE RAIL GUIDE PLATE

B – PINE STRIPS 0.9" WIDE, 0.45" DEEP, 10" LONG
D – FRONT CATHODE RAIL GUIDE PLATE
F – 24 OFF 1mm HOLES IN FRONT AND REAR CATHODE RAIL GUIDE PLATES
ALL DIMENSIONS IN INCHES UNLESS OTHERWISE SPECIFIED @ 1/4 SCALE

VIEW FROM TOP

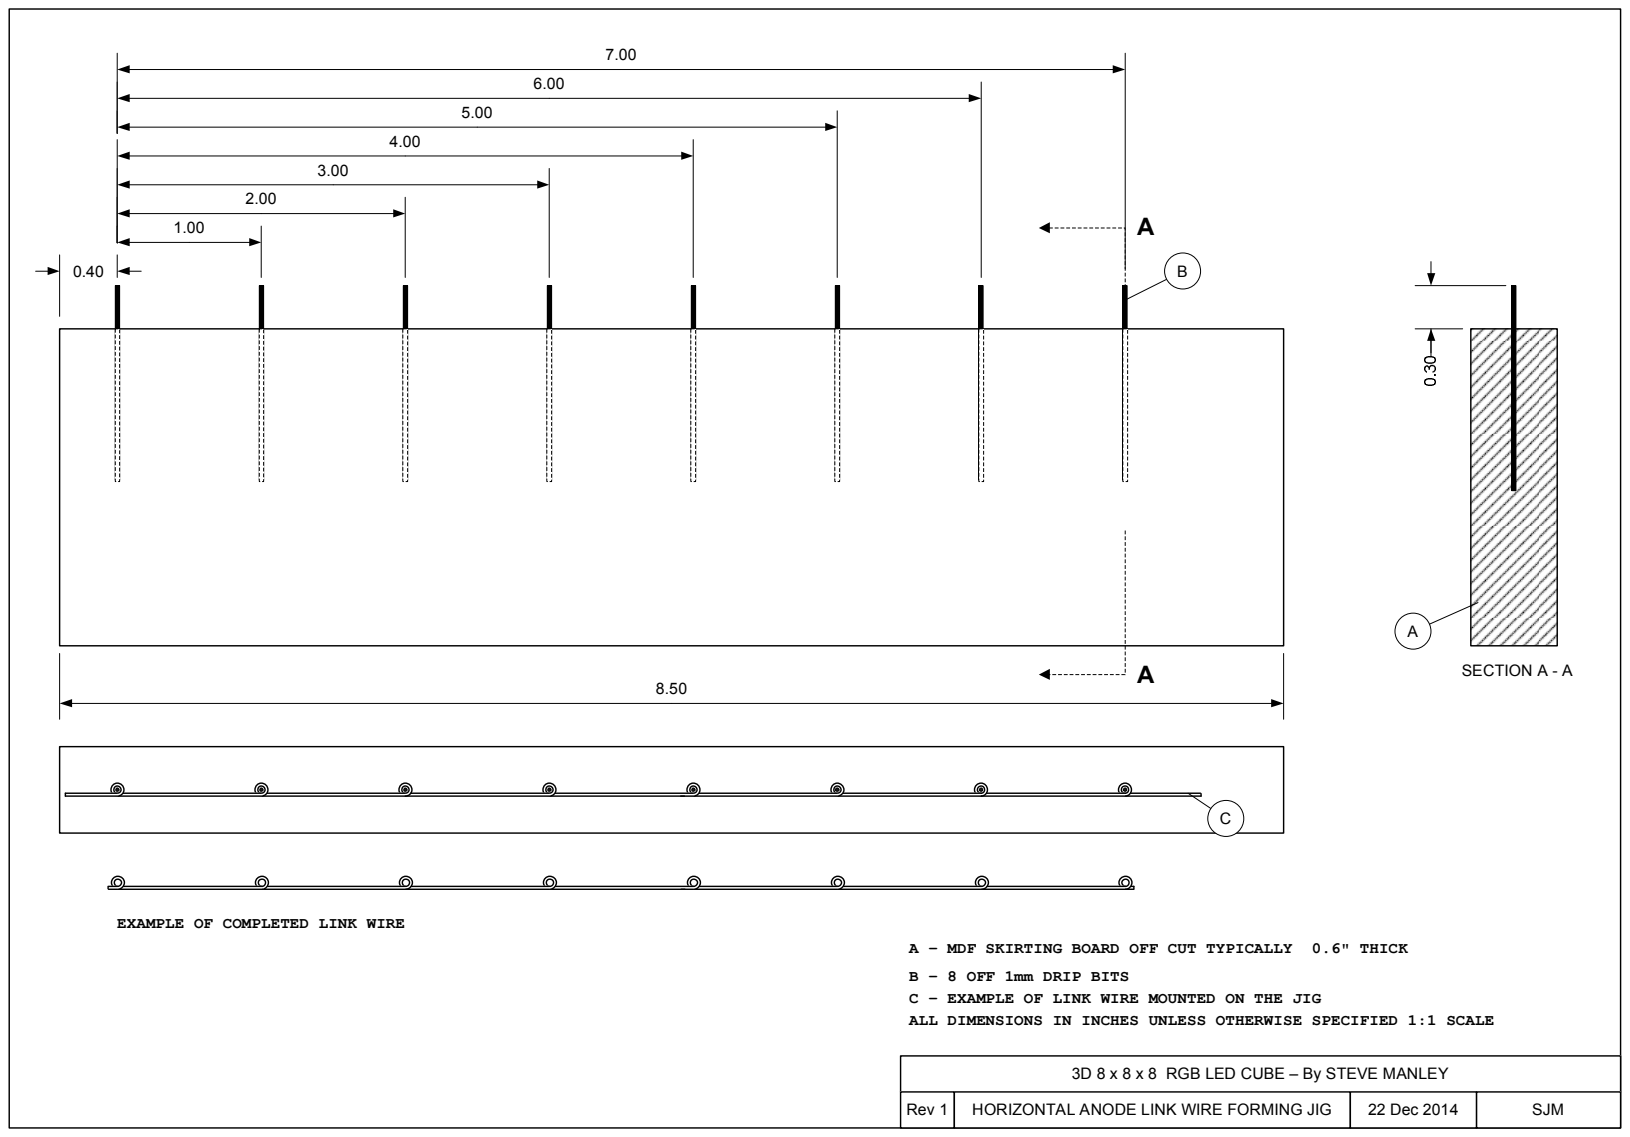
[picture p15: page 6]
Rev 1; HORIZONTAL ANODE LINK WIRE FORMING JIG; 22 Dec 2014; SJM; SECTION A - A; A – MDF SKIRTING BOARD OFF CUT TYPICALLY; 0.6" THICK

EXAMPLE OF COMPLETED LINK WIRE

B – 8 OFF 1mm DRIP BITS

C – EXAMPLE OF LINK WIRE MOUNTED ON THE JIG

ALL DIMENSIONS IN INCHES UNLESS OTHERWISE SPECIFIED 1:1 SCALE

3D 8 x 8 x 8 RGB LED CUBE – By STEVE MANLEY

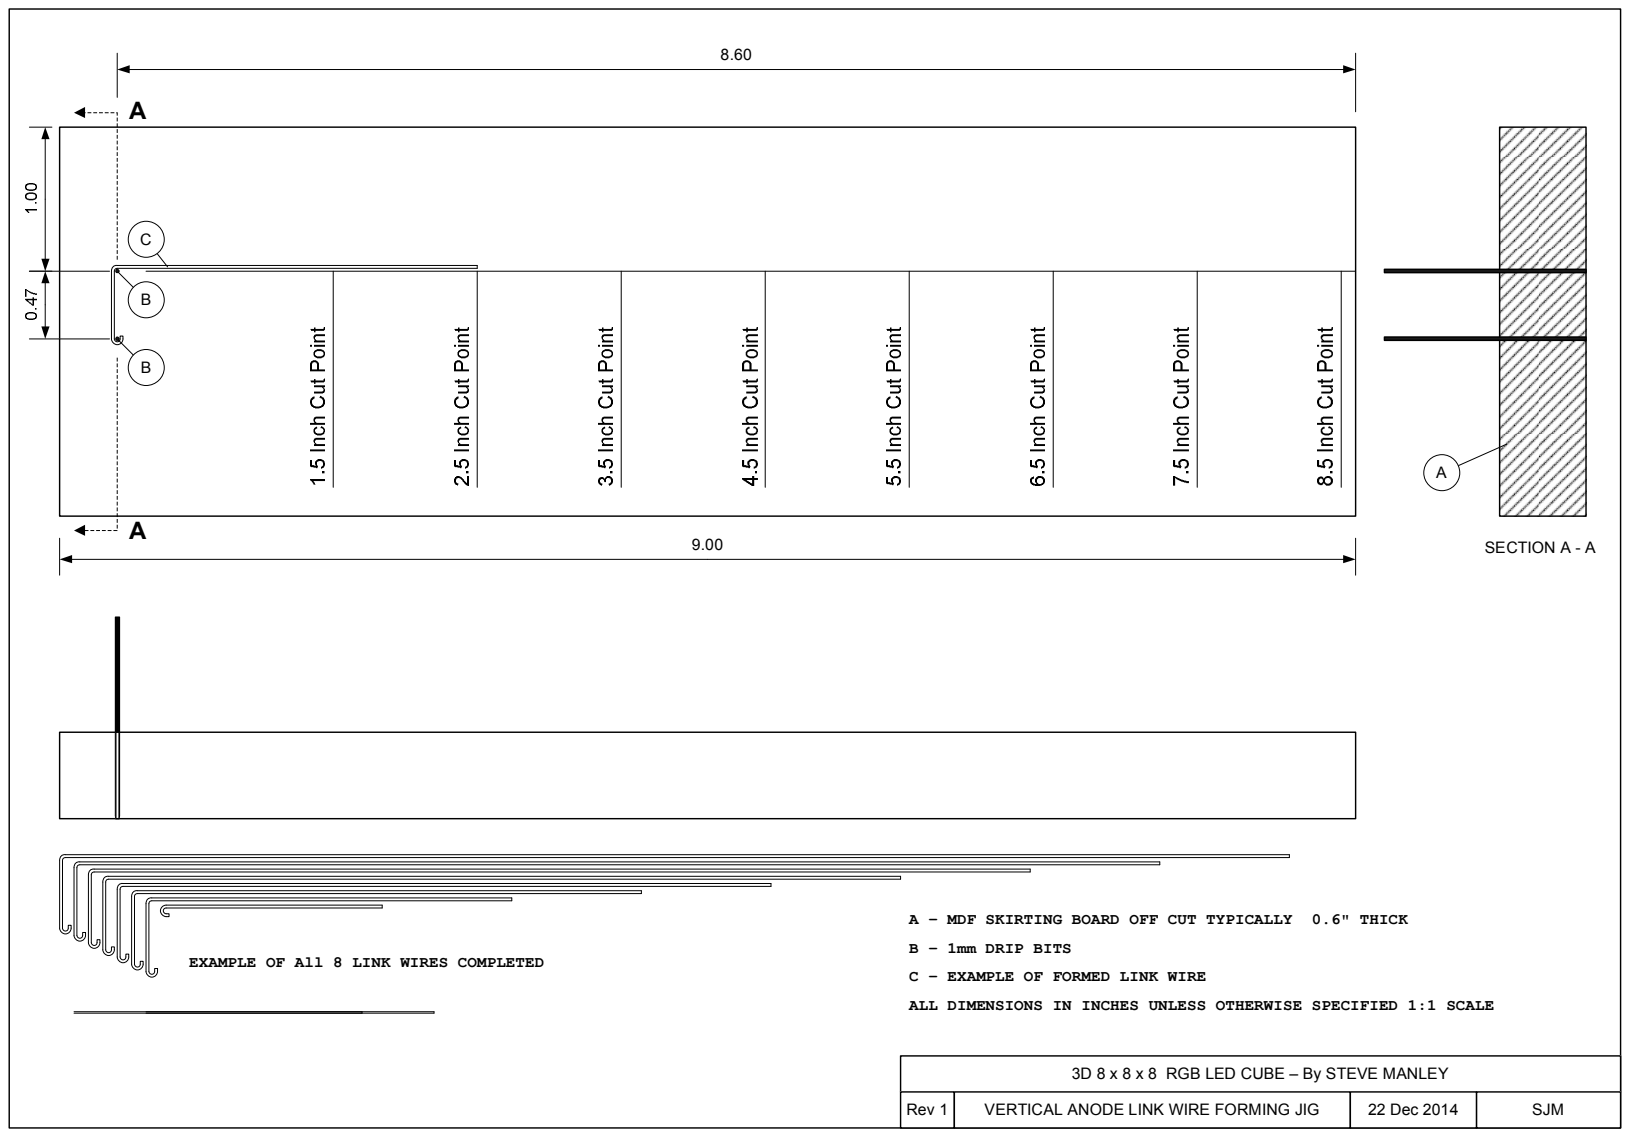
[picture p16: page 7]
Rev 1; VERTICAL ANODE LINK WIRE FORMING JIG; 22 Dec 2014; SJM; SECTION A - A; A – MDF SKIRTING BOARD OFF CUT TYPICALLY; 0.6" THICK; B – 1mm DRIP BITS

EXAMPLE OF All 8 LINK WIRES COMPLETED

C – EXAMPLE OF FORMED LINK WIRE

ALL DIMENSIONS IN INCHES UNLESS OTHERWISE SPECIFIED 1:1 SCALE

3D 8 x 8 x 8 RGB LED CUBE – By STEVE MANLEY

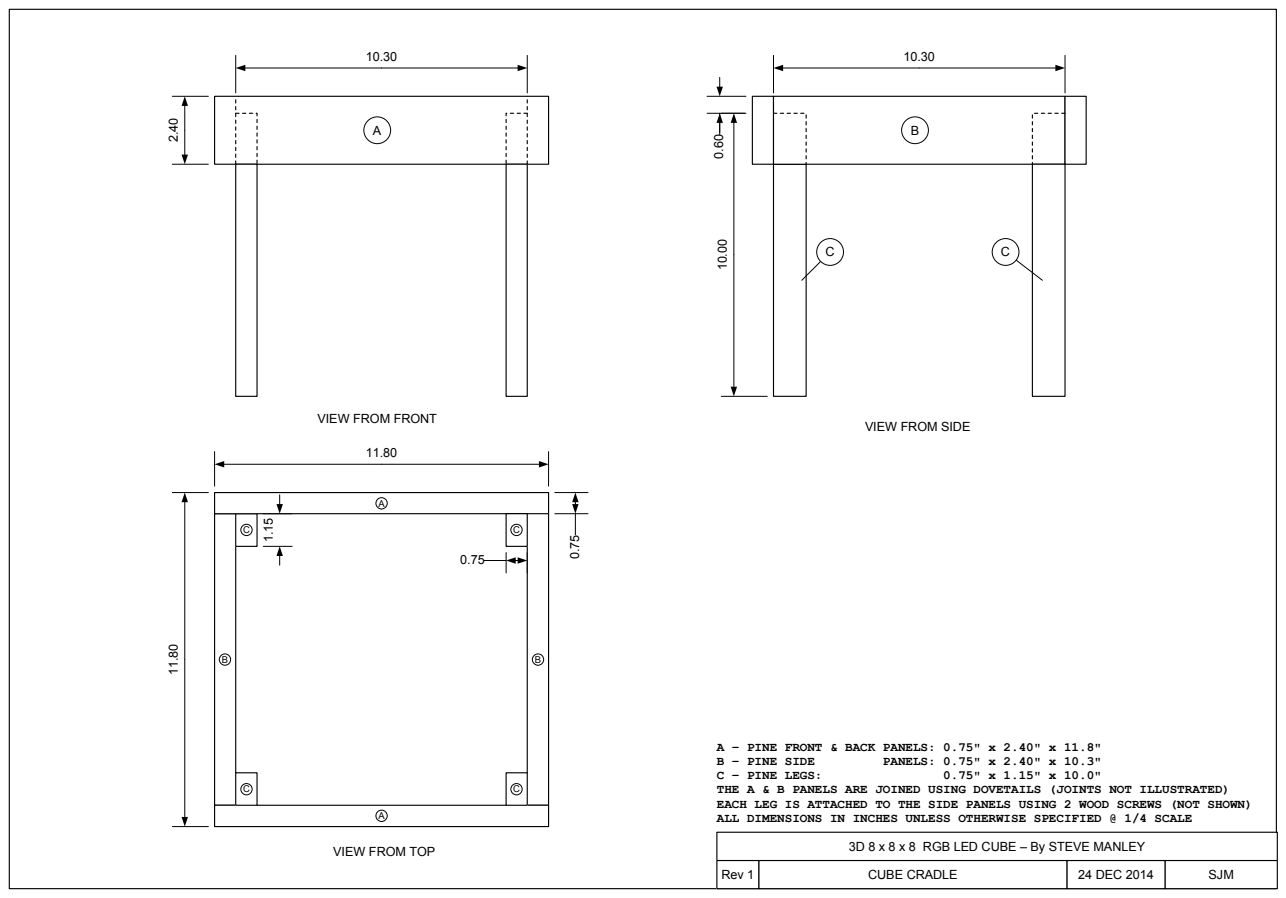
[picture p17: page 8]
Rev 1; CUBE CRADLE; 24 DEC 2014; SJM; C – PINE LEGS:; B – PINE SIDE; PANELS: 0.75" x 2.40" x 10.3"; VIEW FROM FRONT; VIEW FROM SIDE

A – PINE FRONT & BACK PANELS: 0.75" x 2.40" x 11.8"
THE A & B PANELS ARE JOINED USING DOVETAILS (JOINTS NOT ILLUSTRATED)
EACH LEG IS ATTACHED TO THE SIDE PANELS USING 2 WOOD SCREWS (NOT SHOWN)
ALL DIMENSIONS IN INCHES UNLESS OTHERWISE SPECIFIED @ 1/4 SCALE

VIEW FROM TOP

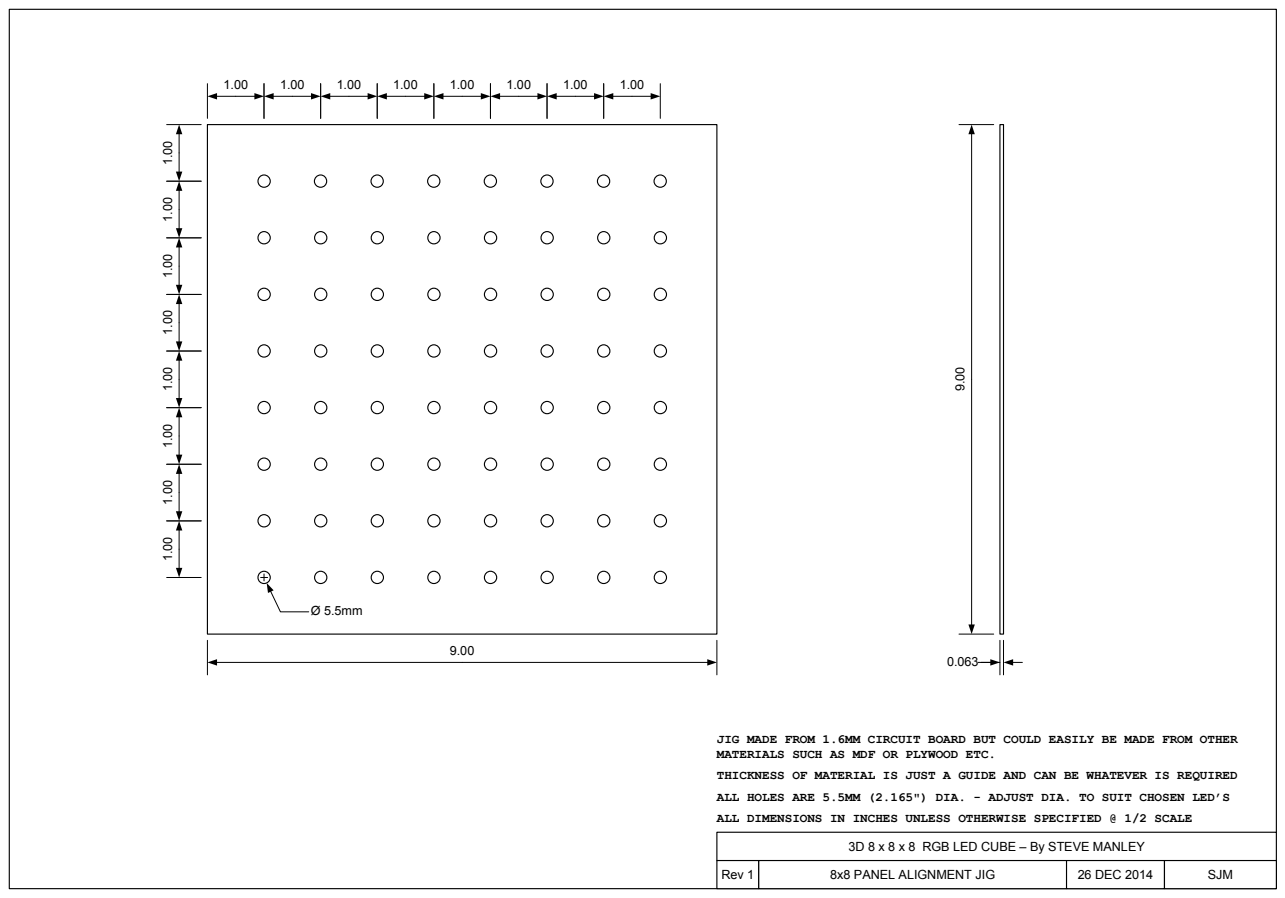
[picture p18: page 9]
Rev 1; 8x8 PANEL ALIGNMENT JIG; 26 DEC 2014; SJM

JIG MADE FROM 1.6MM CIRCUIT BOARD BUT COULD EASILY BE MADE FROM OTHER
MATERIALS SUCH AS MDF OR PLYWOOD ETC.
THICKNESS OF MATERIAL IS JUST A GUIDE AND CAN BE WHATEVER IS REQUIRED

ALL HOLES ARE 5.5MM (2.165") DIA. - ADJUST DIA. TO SUIT CHOSEN LED’S

ALL DIMENSIONS IN INCHES UNLESS OTHERWISE SPECIFIED @ 1/2 SCALE

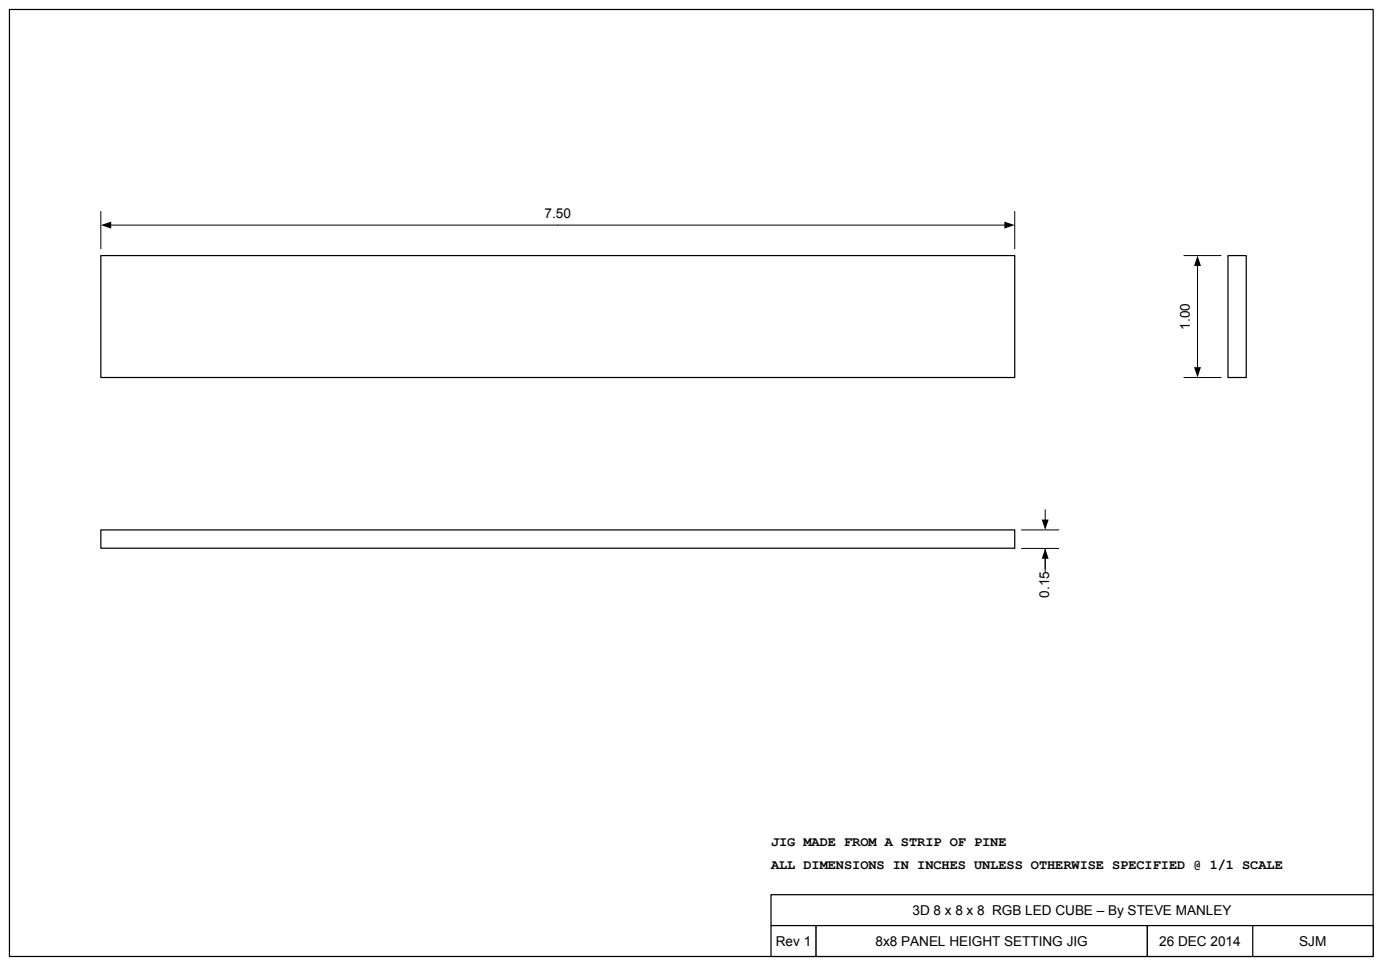
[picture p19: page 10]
Rev 1; 8x8 PANEL HEIGHT SETTING JIG; 26 DEC 2014; SJM

JIG MADE FROM A STRIP OF PINE

ALL DIMENSIONS IN INCHES UNLESS OTHERWISE SPECIFIED @ 1/1 SCALE

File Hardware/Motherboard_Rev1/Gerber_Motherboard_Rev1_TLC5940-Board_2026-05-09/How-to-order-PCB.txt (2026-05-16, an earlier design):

How to Order PCB

Please refer to:
https://docs.easyeda.com/en/PCB/Order-PCB

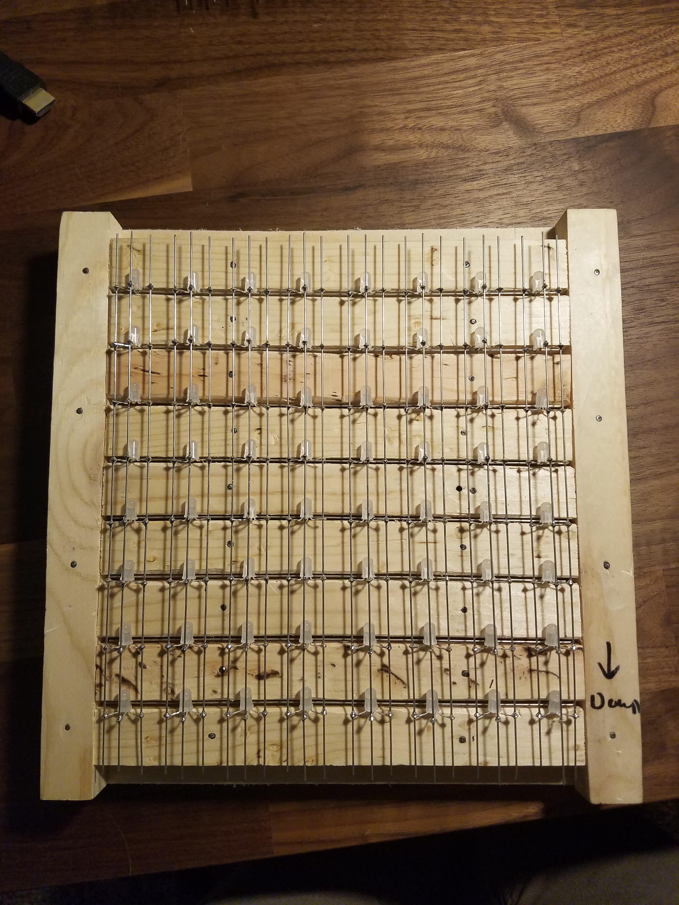
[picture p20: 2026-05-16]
Project Photos/Phase 1 Cube Build/03 Vertical Panel Making/20180319_184357.jpg

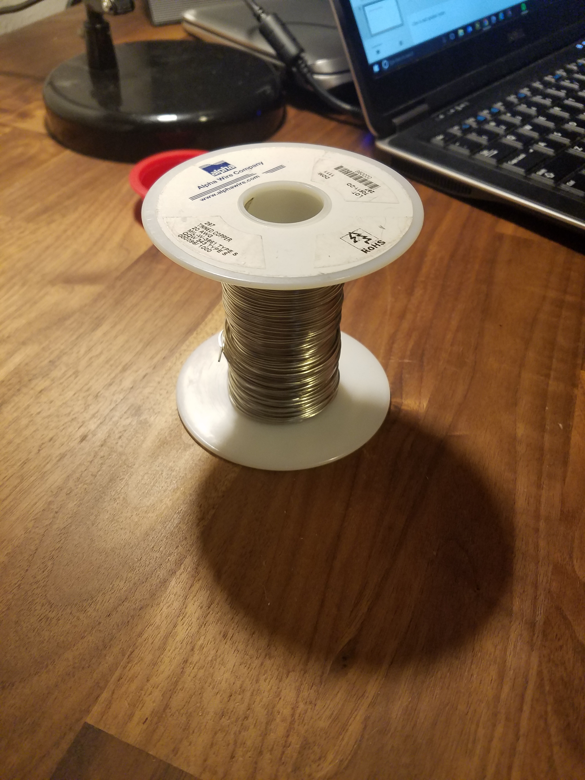
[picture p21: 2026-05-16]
Project Photos/Phase 1 Cube Build/02 Strip Making/20180319_185648.jpg

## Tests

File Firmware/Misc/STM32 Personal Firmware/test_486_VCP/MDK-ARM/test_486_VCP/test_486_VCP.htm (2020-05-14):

# Static Call Graph for image test_486_VCP\test_486_VCP.axf

#<CALLGRAPH># ARM Linker, 5060750: Last Updated: Fri Feb 22 09:38:29 2019

### Maximum Stack Usage = 320 bytes + Unknown(Cycles, Untraceable Function Pointers)

### Call chain for Maximum Stack Depth:

main ⇒ SystemClock_Config ⇒ HAL_RCC_OscConfig ⇒ HAL_InitTick ⇒ HAL_NVIC_SetPriority

### Mutually Recursive functions

- ADC1_2_IRQHandler ⇒ ADC1_2_IRQHandler
- BusFault_Handler ⇒ BusFault_Handler
- HardFault_Handler ⇒ HardFault_Handler
- MemManage_Handler ⇒ MemManage_Handler
- UsageFault_Handler ⇒ UsageFault_Handler

### Function Pointers

- ADC1_2_IRQHandler from startup_stm32l486xx.o(.text) referenced from startup_stm32l486xx.o(RESET)
- ADC3_IRQHandler from startup_stm32l486xx.o(.text) referenced from startup_stm32l486xx.o(RESET)
- AES_IRQHandler from startup_stm32l486xx.o(.text) referenced from startup_stm32l486xx.o(RESET)
- BusFault_Handler from stm32l4xx_it.o(i.BusFault_Handler) referenced from startup_stm32l486xx.o(RESET)
- CAN1_RX0_IRQHandler from startup_stm32l486xx.o(.text) referenced from startup_stm32l486xx.o(RESET)
- CAN1_RX1_IRQHandler from startup_stm32l486xx.o(.text) referenced from startup_stm32l486xx.o(RESET)
- CAN1_SCE_IRQHandler from startup_stm32l486xx.o(.text) referenced from startup_stm32l486xx.o(RESET)
- CAN1_TX_IRQHandler from startup_stm32l486xx.o(.text) referenced from startup_stm32l486xx.o(RESET)
- COMP_IRQHandler from startup_stm32l486xx.o(.text) referenced from startup_stm32l486xx.o(RESET)
- DFSDM1_FLT0_IRQHandler from startup_stm32l486xx.o(.text) referenced from startup_stm32l486xx.o(RESET)
- DFSDM1_FLT1_IRQHandler from startup_stm32l486xx.o(.text) referenced from startup_stm32l486xx.o(RESET)
- DFSDM1_FLT2_IRQHandler from startup_stm32l486xx.o(.text) referenced from startup_stm32l486xx.o(RESET)
- DFSDM1_FLT3_IRQHandler from startup_stm32l486xx.o(.text) referenced from startup_stm32l486xx.o(RESET)
- DMA1_Channel1_IRQHandler from startup_stm32l486xx.o(.text) referenced from startup_stm32l486xx.o(RESET)
- DMA1_Channel2_IRQHandler from startup_stm32l486xx.o(.text) referenced from startup_stm32l486xx.o(RESET)
- DMA1_Channel3_IRQHandler from startup_stm32l486xx.o(.text) referenced from startup_stm32l486xx.o(RESET)
- DMA1_Channel4_IRQHandler from startup_stm32l486xx.o(.text) referenced from startup_stm32l486xx.o(RESET)
- DMA1_Channel5_IRQHandler from startup_stm32l486xx.o(.text) referenced from startup_stm32l486xx.o(RESET)
- DMA1_Channel6_IRQHandler from startup_stm32l486xx.o(.text) referenced from startup_stm32l486xx.o(RESET)
- DMA1_Channel7_IRQHandler from startup_stm32l486xx.o(.text) referenced from startup_stm32l486xx.o(RESET)
- DMA2_Channel1_IRQHandler from startup_stm32l486xx.o(.text) referenced from startup_stm32l486xx.o(RESET)
- DMA2_Channel2_IRQHandler from startup_stm32l486xx.o(.text) referenced from startup_stm32l486xx.o(RESET)
- DMA2_Channel3_IRQHandler from startup_stm32l486xx.o(.text) referenced from startup_stm32l486xx.o(RESET)
- DMA2_Channel4_IRQHandler from startup_stm32l486xx.o(.text) referenced from startup_stm32l486xx.o(RESET)
- DMA2_Channel5_IRQHandler from startup_stm32l486xx.o(.text) referenced from startup_stm32l486xx.o(RESET)
- DMA2_Channel6_IRQHandler from startup_stm32l486xx.o(.text) referenced from startup_stm32l486xx.o(RESET)
- DMA2_Channel7_IRQHandler from startup_stm32l486xx.o(.text) referenced from startup_stm32l486xx.o(RESET)
- DebugMon_Handler from stm32l4xx_it.o(i.DebugMon_Handler) referenced from startup_stm32l486xx.o(RESET)
- EXTI0_IRQHandler from startup_stm32l486xx.o(.text) referenced from startup_stm32l486xx.o(RESET)
- EXTI15_10_IRQHandler from startup_stm32l486xx.o(.text) referenced from startup_stm32l486xx.o(RESET)
- EXTI1_IRQHandler from startup_stm32l486xx.o(.text) referenced from startup_stm32l486xx.o(RESET)
- EXTI2_IRQHandler from startup_stm32l486xx.o(.text) referenced from startup_stm32l486xx.o(RESET)
- EXTI3_IRQHandler from startup_stm32l486xx.o(.text) referenced from startup_stm32l486xx.o(RESET)
- EXTI4_IRQHandler from startup_stm32l486xx.o(.text) referenced from startup_stm32l486xx.o(RESET)
- EXTI9_5_IRQHandler from startup_stm32l486xx.o(.text) referenced from startup_stm32l486xx.o(RESET)
- FLASH_IRQHandler from startup_stm32l486xx.o(.text) referenced from startup_stm32l486xx.o(RESET)
- FMC_IRQHandler from startup_stm32l486xx.o(.text) referenced from startup_stm32l486xx.o(RESET)
- FPU_IRQHandler from startup_stm32l486xx.o(.text) referenced from startup_stm32l486xx.o(RESET)
- HardFault_Handler from stm32l4xx_it.o(i.HardFault_Handler) referenced from startup_stm32l486xx.o(RESET)
- I2C1_ER_IRQHandler from startup_stm32l486xx.o(.text) referenced from startup_stm32l486xx.o(RESET)
- I2C1_EV_IRQHandler from startup_stm32l486xx.o(.text) referenced from startup_stm32l486xx.o(RESET)
- I2C2_ER_IRQHandler from startup_stm32l486xx.o(.text) referenced from startup_stm32l486xx.o(RESET)
- I2C2_EV_IRQHandler from startup_stm32l486xx.o(.text) referenced from startup_stm32l486xx.o(RESET)
- I2C3_ER_IRQHandler from startup_stm32l486xx.o(.text) referenced from startup_stm32l486xx.o(RESET)
- I2C3_EV_IRQHandler from startup_stm32l486xx.o(.text) referenced from startup_stm32l486xx.o(RESET)
- LCD_IRQHandler from startup_stm32l486xx.o(.text) referenced from startup_stm32l486xx.o(RESET)
- LPTIM1_IRQHandler from startup_stm32l486xx.o(.text) referenced from startup_stm32l486xx.o(RESET)
- LPTIM2_IRQHandler from startup_stm32l486xx.o(.text) referenced from startup_stm32l486xx.o(RESET)
- LPUART1_IRQHandler from startup_stm32l486xx.o(.text) referenced from startup_stm32l486xx.o(RESET)
- MemManage_Handler from stm32l4xx_it.o(i.MemManage_Handler) referenced from startup_stm32l486xx.o(RESET)
- NMI_Handler from stm32l4xx_it.o(i.NMI_Handler) referenced from startup_stm32l486xx.o(RESET)
- OTG_FS_IRQHandler from startup_stm32l486xx.o(.text) referenced from startup_stm32l486xx.o(RESET)
- PVD_PVM_IRQHandler from startup_stm32l486xx.o(.text) referenced from startup_stm32l486xx.o(RESET)
- PendSV_Handler from stm32l4xx_it.o(i.PendSV_Handler) referenced from startup_stm32l486xx.o(RESET)
- QUADSPI_IRQHandler from startup_stm32l486xx.o(.text) referenced from startup_stm32l486xx.o(RESET)
- RCC_IRQHandler from startup_stm32l486xx.o(.text) referenced from startup_stm32l486xx.o(RESET)
- RNG_IRQHandler from startup_stm32l486xx.o(.text) referenced from startup_stm32l486xx.o(RESET)
- RTC_Alarm_IRQHandler from startup_stm32l486xx.o(.text) referenced from startup_stm32l486xx.o(RESET)
- RTC_WKUP_IRQHandler from startup_stm32l486xx.o(.text) referenced from startup_stm32l486xx.o(RESET)
- Reset_Handler from startup_stm32l486xx.o(.text) referenced from startup_stm32l486xx.o(RESET)
- SAI1_IRQHandler from startup_stm32l486xx.o(.text) referenced from startup_stm32l486xx.o(RESET)
- SAI2_IRQHandler from startup_stm32l486xx.o(.text) referenced from startup_stm32l486xx.o(RESET)
- SDMMC1_IRQHandler from startup_stm32l486xx.o(.text) referenced from startup_stm32l486xx.o(RESET)
- SPI1_IRQHandler from startup_stm32l486xx.o(.text) referenced from startup_stm32l486xx.o(RESET)
- SPI2_IRQHandler from startup_stm32l486xx.o(.text) referenced from startup_stm32l486xx.o(RESET)
- SPI3_IRQHandler from startup_stm32l486xx.o(.text) referenced from startup_stm32l486xx.o(RESET)
- SVC_Handler from stm32l4xx_it.o(i.SVC_Handler) referenced from startup_stm32l486xx.o(RESET)
- SWPMI1_IRQHandler from startup_stm32l486xx.o(.text) referenced from startup_stm32l486xx.o(RESET)
- SysTick_Handler from stm32l4xx_it.o(i.SysTick_Handler) referenced from startup_stm32l486xx.o(RESET)
- SystemInit from system_stm32l4xx.o(i.SystemInit) referenced from startup_stm32l486xx.o(.text)
- TAMP_STAMP_IRQHandler from startup_stm32l486xx.o(.text) referenced from startup_stm32l486xx.o(RESET)
- TIM1_BRK_TIM15_IRQHandler from startup_stm32l486xx.o(.text) referenced from startup_stm32l486xx.o(RESET)
- TIM1_CC_IRQHandler from startup_stm32l486xx.o(.text) referenced from startup_stm32l486xx.o(RESET)
- TIM1_TRG_COM_TIM17_IRQHandler from startup_stm32l486xx.o(.text) referenced from startup_stm32l486xx.o(RESET)
- TIM1_UP_TIM16_IRQHandler from startup_stm32l486xx.o(.text) referenced from startup_stm32l486xx.o(RESET)
- TIM2_IRQHandler from startup_stm32l486xx.o(.text) referenced from startup_stm32l486xx.o(RESET)
- TIM3_IRQHandler from startup_stm32l486xx.o(.text) referenced from startup_stm32l486xx.o(RESET)
- TIM4_IRQHandler from startup_stm32l486xx.o(.text) referenced from startup_stm32l486xx.o(RESET)
- TIM5_IRQHandler from startup_stm32l486xx.o(.text) referenced from startup_stm32l486xx.o(RESET)
- TIM6_DAC_IRQHandler from startup_stm32l486xx.o(.text) referenced from startup_stm32l486xx.o(RESET)
- TIM7_IRQHandler from startup_stm32l486xx.o(.text) referenced from startup_stm32l486xx.o(RESET)
- TIM8_BRK_IRQHandler from startup_stm32l486xx.o(.text) referenced from startup_stm32l486xx.o(RESET)
- TIM8_CC_IRQHandler from startup_stm32l486xx.o(.text) referenced from startup_stm32l486xx.o(RESET)
- TIM8_TRG_COM_IRQHandler from startup_stm32l486xx.o(.text) referenced from startup_stm32l486xx.o(RESET)
- TIM8_UP_IRQHandler from startup_stm32l486xx.o(.text) referenced from startup_stm32l486xx.o(RESET)
- TSC_IRQHandler from startup_stm32l486xx.o(.text) referenced from startup_stm32l486xx.o(RESET)
- UART4_IRQHandler from startup_stm32l486xx.o(.text) referenced from startup_stm32l486xx.o(RESET)
- UART5_IRQHandler from startup_stm32l486xx.o(.text) referenced from startup_stm32l486xx.o(RESET)
- USART1_IRQHandler from startup_stm32l486xx.o(.text) referenced from startup_stm32l486xx.o(RESET)
- USART2_IRQHandler from startup_stm32l486xx.o(.text) referenced from startup_stm32l486xx.o(RESET)
- USART3_IRQHandler from startup_stm32l486xx.o(.text) referenced from startup_stm32l486xx.o(RESET)
- UsageFault_Handler from stm32l4xx_it.o(i.UsageFault_Handler) referenced from startup_stm32l486xx.o(RESET)
- WWDG_IRQHandler from startup_stm32l486xx.o(.text) referenced from startup_stm32l486xx.o(RESET)
- __main from entry.o(.ARM.Collect$$$$00000000) referenced from startup_stm32l486xx.o(.text)
- main from main.o(i.main) referenced from entry9a.o(.ARM.Collect$$$$0000000B)

### Global Symbols

__main (Thumb, 0 bytes, Stack size unknown bytes, entry.o(.ARM.Collect$$$$00000000))
[Address Reference Count : 1]

- startup_stm32l486xx.o(.text)

_main_stk (Thumb, 0 bytes, Stack size unknown bytes, entry2.o(.ARM.Collect$$$$00000001))

_main_scatterload (Thumb, 0 bytes, Stack size unknown bytes, entry5.o(.ARM.Collect$$$$00000004))

[Calls]

- >> __scatterload

__main_after_scatterload (Thumb, 0 bytes, Stack size unknown bytes, entry5.o(.ARM.Collect$$$$00000004))

[Called By]

- >> __scatterload

_main_clock (Thumb, 0 bytes, Stack size unknown bytes, entry7b.o(.ARM.Collect$$$$00000008))

_main_cpp_init (Thumb, 0 bytes, Stack size unknown bytes, entry8b.o(.ARM.Collect$$$$0000000A))

_main_init (Thumb, 0 bytes, Stack size unknown bytes, entry9a.o(.ARM.Collect$$$$0000000B))

__rt_final_cpp (Thumb, 0 bytes, Stack size unknown bytes, entry10a.o(.ARM.Collect$$$$0000000D))

__rt_final_exit (Thumb, 0 bytes, Stack size unknown bytes, entry11a.o(.ARM.Collect$$$$0000000F))

Reset_Handler (Thumb, 8 bytes, Stack size 0 bytes, startup_stm32l486xx.o(.text))
[Address Reference Count : 1]

- startup_stm32l486xx.o(RESET)

ADC1_2_IRQHandler (Thumb, 0 bytes, Stack size 0 bytes, startup_stm32l486xx.o(.text))

[Calls]

- >> ADC1_2_IRQHandler

[Called By]

- >> ADC1_2_IRQHandler

[Address Reference Count : 1]

- startup_stm32l486xx.o(RESET)

ADC3_IRQHandler (Thumb, 0 bytes, Stack size 0 bytes, startup_stm32l486xx.o(.text))
[Address Reference Count : 1]

- startup_stm32l486xx.o(RESET)

AES_IRQHandler (Thumb, 0 bytes, Stack size 0 bytes, startup_stm32l486xx.o(.text))
[Address Reference Count : 1]

- startup_stm32l486xx.o(RESET)

CAN1_RX0_IRQHandler (Thumb, 0 bytes, Stack size 0 bytes, startup_stm32l486xx.o(.text))
[Address Reference Count : 1]

- startup_stm32l486xx.o(RESET)

CAN1_RX1_IRQHandler (Thumb, 0 bytes, Stack size 0 bytes, startup_stm32l486xx.o(.text))
[Address Reference Count : 1]

- startup_stm32l486xx.o(RESET)

CAN1_SCE_IRQHandler (Thumb, 0 bytes, Stack size 0 bytes, startup_stm32l486xx.o(.text))
[Address Reference Count : 1]

- startup_stm32l486xx.o(RESET)

CAN1_TX_IRQHandler (Thumb, 0 bytes, Stack size 0 bytes, startup_stm32l486xx.o(.text))
[Address Reference Count : 1]

- startup_stm32l486xx.o(RESET)

COMP_IRQHandler (Thumb, 0 bytes, Stack size 0 bytes, startup_stm32l486xx.o(.text))
[Address Reference Count : 1]

- startup_stm32l486xx.o(RESET)

DFSDM1_FLT0_IRQHandler (Thumb, 0 bytes, Stack size 0 bytes, startup_stm32l486xx.o(.text))
[Address Reference Count : 1]

- startup_stm32l486xx.o(RESET)

DFSDM1_FLT1_IRQHandler (Thumb, 0 bytes, Stack size 0 bytes, startup_stm32l486xx.o(.text))
[Address Reference Count : 1]

- startup_stm32l486xx.o(RESET)

DFSDM1_FLT2_IRQHandler (Thumb, 0 bytes, Stack size 0 bytes, startup_stm32l486xx.o(.text))
[Address Reference Count : 1]

- startup_stm32l486xx.o(RESET)

DFSDM1_FLT3_IRQHandler (Thumb, 0 bytes, Stack size 0 bytes, startup_stm32l486xx.o(.text))
[Address Reference Count : 1]

- startup_stm32l486xx.o(RESET)

DMA1_Channel1_IRQHandler (Thumb, 0 bytes, Stack size 0 bytes, startup_stm32l486xx.o(.text))
[Address Reference Count : 1]

- startup_stm32l486xx.o(RESET)

DMA1_Channel2_IRQHandler (Thumb, 0 bytes, Stack size 0 bytes, startup_stm32l486xx.o(.text))
[Address Reference Count : 1]

- startup_stm32l486xx.o(RESET)

DMA1_Channel3_IRQHandler (Thumb, 0 bytes, Stack size 0 bytes, startup_stm32l486xx.o(.text))
[Address Reference Count : 1]

- startup_stm32l486xx.o(RESET)

DMA1_Channel4_IRQHandler (Thumb, 0 bytes, Stack size 0 bytes, startup_stm32l486xx.o(.text))
[Address Reference Count : 1]

- startup_stm32l486xx.o(RESET)

DMA1_Channel5_IRQHandler (Thumb, 0 bytes, Stack size 0 bytes, startup_stm32l486xx.o(.text))
[Address Reference Count : 1]

- startup_stm32l486xx.o(RESET)

DMA1_Channel6_IRQHandler (Thumb, 0 bytes, Stack size 0 bytes, startup_stm32l486xx.o(.text))
[Address Reference Count : 1]

- startup_stm32l486xx.o(RESET)

DMA1_Channel7_IRQHandler (Thumb, 0 bytes, Stack size 0 bytes, startup_stm32l486xx.o(.text))
[Address Reference Count : 1]

- startup_stm32l486xx.o(RESET)

DMA2_Channel1_IRQHandler (Thumb, 0 bytes, Stack size 0 bytes, startup_stm32l486xx.o(.text))
[Address Reference Count : 1]

- startup_stm32l486xx.o(RESET)

DMA2_Channel2_IRQHandler (Thumb, 0 bytes, Stack size 0 bytes, startup_stm32l486xx.o(.text))
[Address Reference Count : 1]

- startup_stm32l486xx.o(RESET)

DMA2_Channel3_IRQHandler (Thumb, 0 bytes, Stack size 0 bytes, startup_stm32l486xx.o(.text))
[Address Reference Count : 1]

- startup_stm32l486xx.o(RESET)

DMA2_Channel4_IRQHandler (Thumb, 0 bytes, Stack size 0 bytes, startup_stm32l486xx.o(.text))
[Address Reference Count : 1]

- startup_stm32l486xx.o(RESET)

DMA2_Channel5_IRQHandler (Thumb, 0 bytes, Stack size 0 bytes, startup_stm32l486xx.o(.text))
[Address Reference Count : 1]

- startup_stm32l486xx.o(RESET)

DMA2_Channel6_IRQHandler (Thumb, 0 bytes, Stack size 0 bytes, startup_stm32l486xx.o(.text))
[Address Reference Count : 1]

- startup_stm32l486xx.o(RESET)

DMA2_Channel7_IRQHandler (Thumb, 0 bytes, Stack size 0 bytes, startup_stm32l486xx.o(.text))
[Address Reference Count : 1]

- startup_stm32l486xx.o(RESET)

EXTI0_IRQHandler (Thumb, 0 bytes, Stack size 0 bytes, startup_stm32l486xx.o(.text))
[Address Reference Count : 1]

- startup_stm32l486xx.o(RESET)

EXTI15_10_IRQHandler (Thumb, 0 bytes, Stack size 0 bytes, startup_stm32l486xx.o(.text))
[Address Reference Count : 1]

- startup_stm32l486xx.o(RESET)

EXTI1_IRQHandler (Thumb, 0 bytes, Stack size 0 bytes, startup_stm32l486xx.o(.text))
[Address Reference Count : 1]

- startup_stm32l486xx.o(RESET)

EXTI2_IRQHandler (Thumb, 0 bytes, Stack size 0 bytes, startup_stm32l486xx.o(.text))
[Address Reference Count : 1]

- startup_stm32l486xx.o(RESET)

EXTI3_IRQHandler (Thumb, 0 bytes, Stack size 0 bytes, startup_stm32l486xx.o(.text))
[Address Reference Count : 1]

- startup_stm32l486xx.o(RESET)

EXTI4_IRQHandler (Thumb, 0 bytes, Stack size 0 bytes, startup_stm32l486xx.o(.text))
[Address Reference Count : 1]

- startup_stm32l486xx.o(RESET)

EXTI9_5_IRQHandler (Thumb, 0 bytes, Stack size 0 bytes, startup_stm32l486xx.o(.text))
[Address Reference Count : 1]

- startup_stm32l486xx.o(RESET)

FLASH_IRQHandler (Thumb, 0 bytes, Stack size 0 bytes, startup_stm32l486xx.o(.text))
[Address Reference Count : 1]

- startup_stm32l486xx.o(RESET)

FMC_IRQHandler (Thumb, 0 bytes, Stack size 0 bytes, startup_stm32l486xx.o(.text))
[Address Reference Count : 1]

- startup_stm32l486xx.o(RESET)

FPU_IRQHandler (Thumb, 0 bytes, Stack size 0 bytes, startup_stm32l486xx.o(.text))
[Address Reference Count : 1]

- startup_stm32l486xx.o(RESET)

I2C1_ER_IRQHandler (Thumb, 0 bytes, Stack size 0 bytes, startup_stm32l486xx.o(.text))
[Address Reference Count : 1]

- startup_stm32l486xx.o(RESET)

I2C1_EV_IRQHandler (Thumb, 0 bytes, Stack size 0 bytes, startup_stm32l486xx.o(.text))
[Address Reference Count : 1]

- startup_stm32l486xx.o(RESET)

I2C2_ER_IRQHandler (Thumb, 0 bytes, Stack size 0 bytes, startup_stm32l486xx.o(.text))
[Address Reference Count : 1]

- startup_stm32l486xx.o(RESET)

I2C2_EV_IRQHandler (Thumb, 0 bytes, Stack size 0 bytes, startup_stm32l486xx.o(.text))
[Address Reference Count : 1]

- startup_stm32l486xx.o(RESET)

I2C3_ER_IRQHandler (Thumb, 0 bytes, Stack size 0 bytes, startup_stm32l486xx.o(.text))
[Address Reference Count : 1]

- startup_stm32l486xx.o(RESET)

I2C3_EV_IRQHandler (Thumb, 0 bytes, Stack size 0 bytes, startup_stm32l486xx.o(.text))
[Address Reference Count : 1]

- startup_stm32l486xx.o(RESET)

LCD_IRQHandler (Thumb, 0 bytes, Stack size 0 bytes, startup_stm32l486xx.o(.text))
[Address Reference Count : 1]

- startup_stm32l486xx.o(RESET)

LPTIM1_IRQHandler (Thumb, 0 bytes, Stack size 0 bytes, startup_stm32l486xx.o(.text))
[Address Reference Count : 1]

- startup_stm32l486xx.o(RESET)

LPTIM2_IRQHandler (Thumb, 0 bytes, Stack size 0 bytes, startup_stm32l486xx.o(.text))
[Address Reference Count : 1]

- startup_stm32l486xx.o(RESET)

LPUART1_IRQHandler (Thumb, 0 bytes, Stack size 0 bytes, startup_stm32l486xx.o(.text))
[Address Reference Count : 1]

- startup_stm32l486xx.o(RESET)

OTG_FS_IRQHandler (Thumb, 0 bytes, Stack size 0 bytes, startup_stm32l486xx.o(.text))
[Address Reference Count : 1]

- startup_stm32l486xx.o(RESET)

PVD_PVM_IRQHandler (Thumb, 0 bytes, Stack size 0 bytes, startup_stm32l486xx.o(.text))
[Address Reference Count : 1]

- startup_stm32l486xx.o(RESET)

QUADSPI_IRQHandler (Thumb, 0 bytes, Stack size 0 bytes, startup_stm32l486xx.o(.text))
[Address Reference Count : 1]

- startup_stm32l486xx.o(RESET)

RCC_IRQHandler (Thumb, 0 bytes, Stack size 0 bytes, startup_stm32l486xx.o(.text))
[Address Reference Count : 1]

- startup_stm32l486xx.o(RESET)

RNG_IRQHandler (Thumb, 0 bytes, Stack size 0 bytes, startup_stm32l486xx.o(.text))
[Address Reference Count : 1]

- startup_stm32l486xx.o(RESET)

RTC_Alarm_IRQHandler (Thumb, 0 bytes, Stack size 0 bytes, startup_stm32l486xx.o(.text))
[Address Reference Count : 1]

- startup_stm32l486xx.o(RESET)

RTC_WKUP_IRQHandler (Thumb, 0 bytes, Stack size 0 bytes, startup_stm32l486xx.o(.text))
[Address Reference Count : 1]

- startup_stm32l486xx.o(RESET)

SAI1_IRQHandler (Thumb, 0 bytes, Stack size 0 bytes, startup_stm32l486xx.o(.text))
[Address Reference Count : 1]

- startup_stm32l486xx.o(RESET)

SAI2_IRQHandler (Thumb, 0 bytes, Stack size 0 bytes, startup_stm32l486xx.o(.text))
[Address Reference Count : 1]

- startup_stm32l486xx.o(RESET)

SDMMC1_IRQHandler (Thumb, 0 bytes, Stack size 0 bytes, startup_stm32l486xx.o(.text))
[Address Reference Count : 1]

- startup_stm32l486xx.o(RESET)

SPI1_IRQHandler (Thumb, 0 bytes, Stack size 0 bytes, startup_stm32l486xx.o(.text))
[Address Reference Count : 1]

- startup_stm32l486xx.o(RESET)

SPI2_IRQHandler (Thumb, 0 bytes, Stack size 0 bytes, startup_stm32l486xx.o(.text))
[Address Reference Count : 1]

- startup_stm32l486xx.o(RESET)

SPI3_IRQHandler (Thumb, 0 bytes, Stack size 0 bytes, startup_stm32l486xx.o(.text))
[Address Reference Count : 1]

- startup_stm32l486xx.o(RESET)

SWPMI1_IRQHandler (Thumb, 0 bytes, Stack size 0 bytes, startup_stm32l486xx.o(.text))
[Address Reference Count : 1]

- startup_stm32l486xx.o(RESET)

TAMP_STAMP_IRQHandler (Thumb, 0 bytes, Stack size 0 bytes, startup_stm32l486xx.o(.text))
[Address Reference Count : 1]

- startup_stm32l486xx.o(RESET)

TIM1_BRK_TIM15_IRQHandler (Thumb, 0 bytes, Stack size 0 bytes, startup_stm32l486xx.o(.text))
[Address Reference Count : 1]

- startup_stm32l486xx.o(RESET)

TIM1_CC_IRQHandler (Thumb, 0 bytes, Stack size 0 bytes, startup_stm32l486xx.o(.text))
[Address Reference Count : 1]

- startup_stm32l486xx.o(RESET)

TIM1_TRG_COM_TIM17_IRQHandler (Thumb, 0 bytes, Stack size 0 bytes, startup_stm32l486xx.o(.text))
[Address Reference Count : 1]

- startup_stm32l486xx.o(RESET)

TIM1_UP_TIM16_IRQHandler (Thumb, 0 bytes, Stack size 0 bytes, startup_stm32l486xx.o(.text))
[Address Reference Count : 1]

- startup_stm32l486xx.o(RESET)

TIM2_IRQHandler (Thumb, 0 bytes, Stack size 0 bytes, startup_stm32l486xx.o(.text))
[Address Reference Count : 1]

- startup_stm32l486xx.o(RESET)

TIM3_IRQHandler (Thumb, 0 bytes, Stack size 0 bytes, startup_stm32l486xx.o(.text))
[Address Reference Count : 1]

- startup_stm32l486xx.o(RESET)

TIM4_IRQHandler (Thumb, 0 bytes, Stack size 0 bytes, startup_stm32l486xx.o(.text))
[Address Reference Count : 1]

- startup_stm32l486xx.o(RESET)

TIM5_IRQHandler (Thumb, 0 bytes, Stack size 0 bytes, startup_stm32l486xx.o(.text))
[Address Reference Count : 1]

- startup_stm32l486xx.o(RESET)

TIM6_DAC_IRQHandler (Thumb, 0 bytes, Stack size 0 bytes, startup_stm32l486xx.o(.text))
[Address Reference Count : 1]

- startup_stm32l486xx.o(RESET)

TIM7_IRQHandler (Thumb, 0 bytes, Stack size 0 bytes, startup_stm32l486xx.o(.text))
[Address Reference Count : 1]

- startup_stm32l486xx.o(RESET)

TIM8_BRK_IRQHandler (Thumb, 0 bytes, Stack size 0 bytes, startup_stm32l486xx.o(.text))
[Address Reference Count : 1]

- startup_stm32l486xx.o(RESET)

TIM8_CC_IRQHandler (Thumb, 0 bytes, Stack size 0 bytes, startup_stm32l486xx.o(.text))
[Address Reference Count : 1]

- startup_stm32l486xx.o(RESET)

TIM8_TRG_COM_IRQHandler (Thumb, 0 bytes, Stack size 0 bytes, startup_stm32l486xx.o(.text))
[Address Reference Count : 1]

- startup_stm32l486xx.o(RESET)

TIM8_UP_IRQHandler (Thumb, 0 bytes, Stack size 0 bytes, startup_stm32l486xx.o(.text))
[Address Reference Count : 1]

- startup_stm32l486xx.o(RESET)

TSC_IRQHandler (Thumb, 0 bytes, Stack size 0 bytes, startup_stm32l486xx.o(.text))
[Address Reference Count : 1]

- startup_stm32l486xx.o(RESET)

UART4_IRQHandler (Thumb, 0 bytes, Stack size 0 bytes, startup_stm32l486xx.o(.text))
[Address Reference Count : 1]

- startup_stm32l486xx.o(RESET)

UART5_IRQHandler (Thumb, 0 bytes, Stack size 0 bytes, startup_stm32l486xx.o(.text))
[Address Reference Count : 1]

- startup_stm32l486xx.o(RESET)

USART1_IRQHandler (Thumb, 0 bytes, Stack size 0 bytes, startup_stm32l486xx.o(.text))
[Address Reference Count : 1]

- startup_stm32l486xx.o(RESET)

USART2_IRQHandler (Thumb, 0 bytes, Stack size 0 bytes, startup_stm32l486xx.o(.text))
[Address Reference Count : 1]

- startup_stm32l486xx.o(RESET)

USART3_IRQHandler (Thumb, 0 bytes, Stack size 0 bytes, startup_stm32l486xx.o(.text))
[Address Reference Count : 1]

- startup_stm32l486xx.o(RESET)

WWDG_IRQHandler (Thumb, 0 bytes, Stack size 0 bytes, startup_stm32l486xx.o(.text))
[Address Reference Count : 1]

- startup_stm32l486xx.o(RESET)

__aeabi_memcpy (Thumb, 36 bytes, Stack size 0 bytes, memcpya.o(.text), UNUSED)

__aeabi_memcpy4 (Thumb, 0 bytes, Stack size 0 bytes, memcpya.o(.text))

[Called By]

- >> HAL_HCD_Init

__aeabi_memcpy8 (Thumb, 0 bytes, Stack size 0 bytes, memcpya.o(.text), UNUSED)

__scatterload (Thumb, 28 bytes, Stack size 0 bytes, init.o(.text))

[Calls]

- >> __main_after_scatterload
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

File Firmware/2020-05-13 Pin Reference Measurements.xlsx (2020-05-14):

1 | L5_EN | HIGH
2 | L6_EN | HIGH
3 | L7_EN | HIGH
4 | L8_EN | HIGH
5 | BLANK_3V3 | LOW
6 | ESP8266_RX_STM32_TX | HIGH
7 | ESP8266_TX_STM32_RX | LOW
8 | D- (NC) | floating?
9 | D+ (NC) | floating?
10 | ESP8266_EN | LOW
11 | XERR
12 | KEYPAD_IRQ
13 | WHEEL_IRQ
14 | SCL_+3.3V
15 | SDA_+3.3V
16 | L1_EN
17 | L2_EN
18 | "5V" (NC?)
19 | GND
20 | VMICRO
21 | VBAT (VMICRO)
22 | NC?
23 | OSC32IN
24 | OSC32OUT
25 | A0
26 | GSCLK_3V3
27 | NC
28 | NC
29 | XLAT_3V3
30 | SCLK_3V3
31 | SOUT_3V3
32 | SIN_3V3
33 | DCPRG_3V3
34 | VPRG_3V3
35 | L3_EN
36 | L4_EN
37 | NRST
38 | VMICRO
39 | GND
40 | GND

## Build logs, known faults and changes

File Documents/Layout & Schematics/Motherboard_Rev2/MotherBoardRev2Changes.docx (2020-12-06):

External pullup from Blank to VMICRO – 100k?

- Doesn’t appear to be the problem.
- Might be a tlc init issue due to pulling blank low w/o clearing the registers/setting DC

Put a switch on VLCD so the lcd can be turned off

Put holes in the PCB for the connecter to fit properly

That 8A fuse will probably never blow

Replace the discrete level shifters for the 8 chan TI part

Remove MPR121 circuitry from PCB

Bulk capacitor across VIN

Improve vias under TLCs for better thermal performance

Review GND traces & vias; consider growing some of them

Need better accessibility to SIN & SOUTs and test points from the micro in general

Accessible reset button

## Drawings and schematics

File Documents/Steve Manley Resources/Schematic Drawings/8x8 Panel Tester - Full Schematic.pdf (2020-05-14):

1K

5V

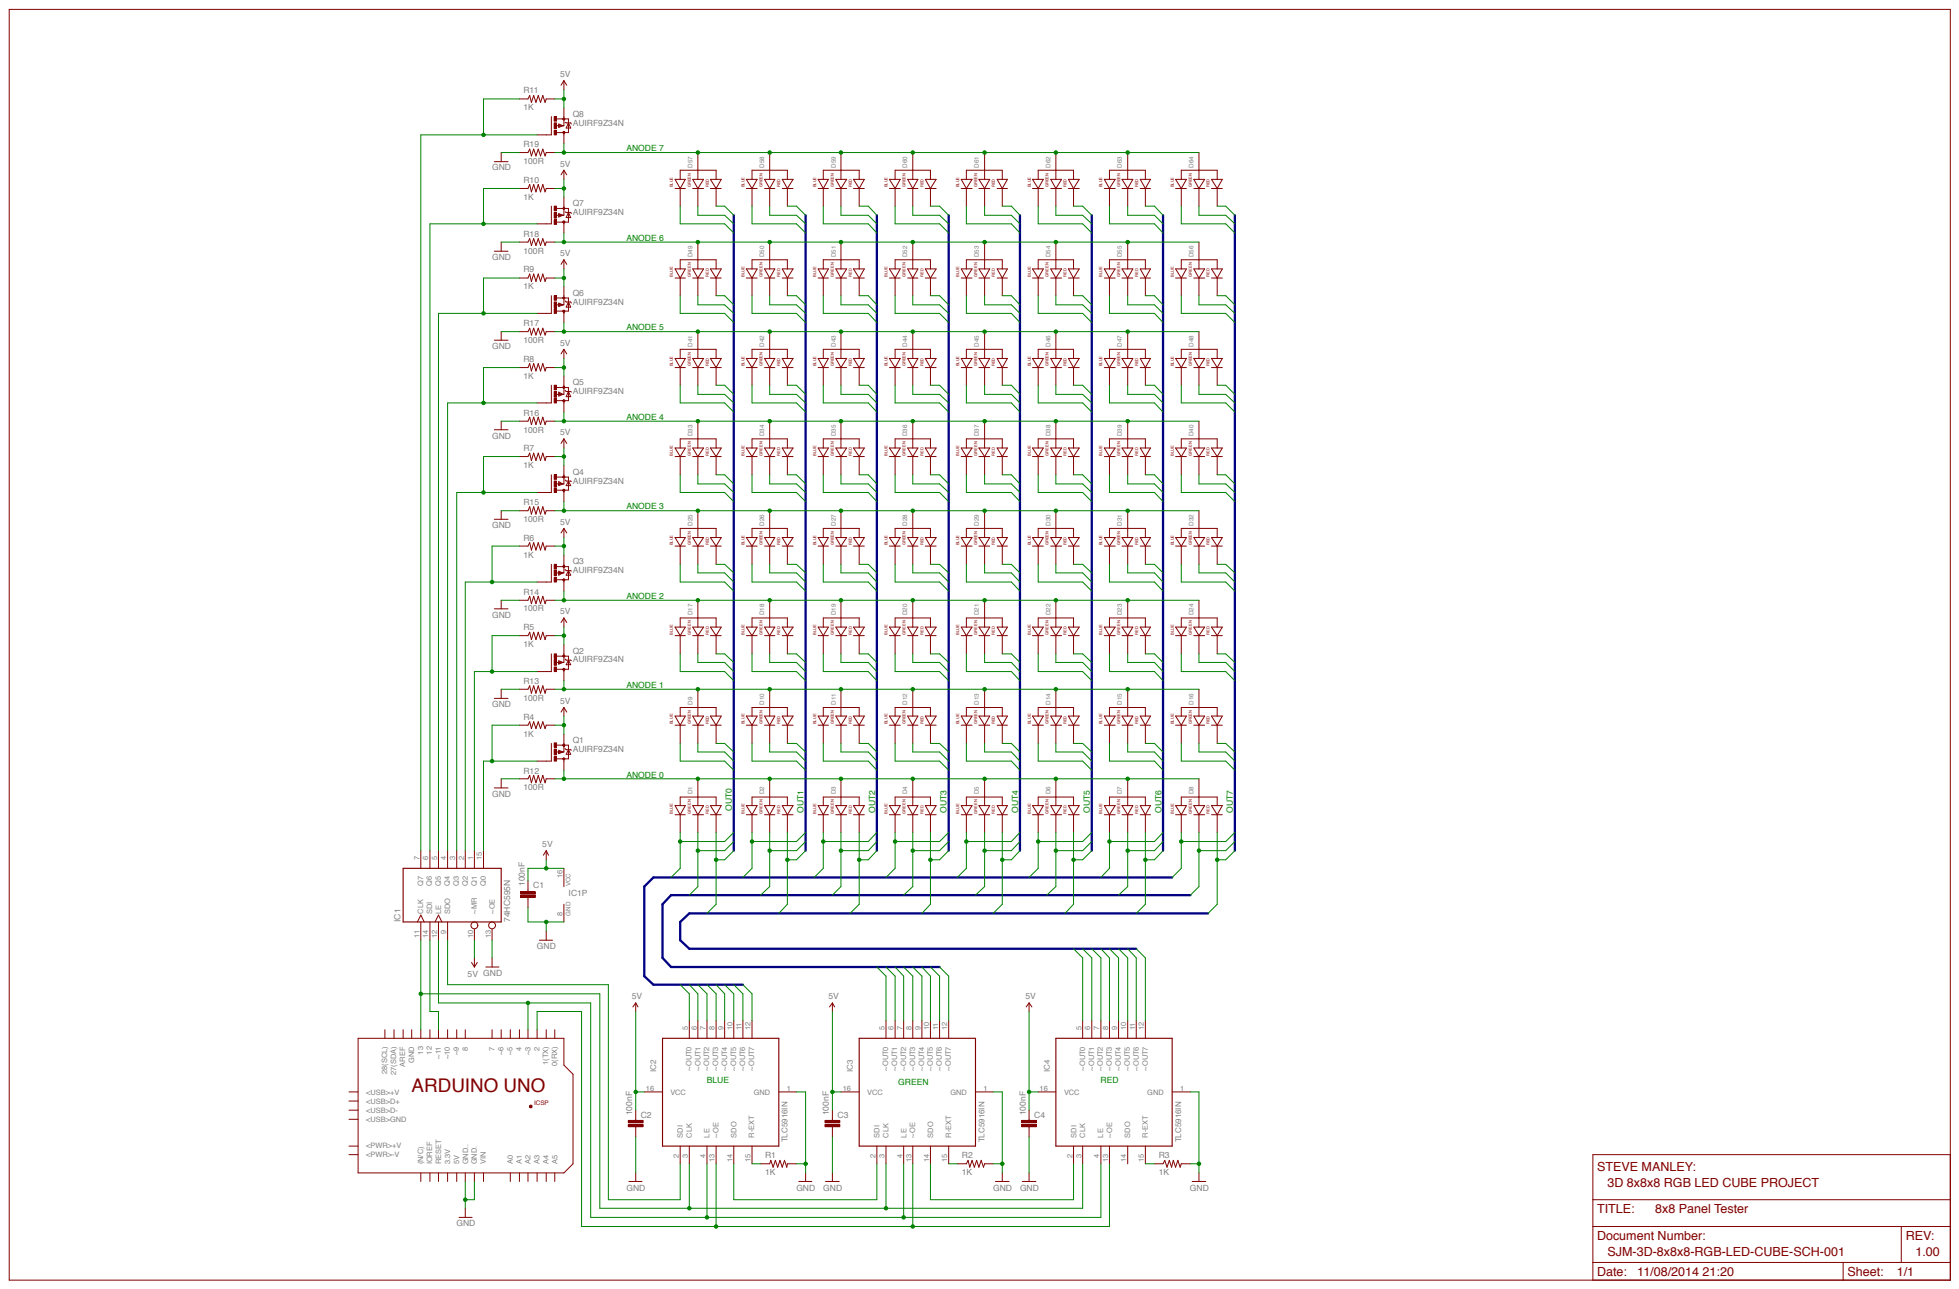
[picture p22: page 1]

STEVE MANLEY:
3D 8x8x8 RGB LED CUBE PROJECT

Document Number: SJM-3D-8x8x8-RGB-LED-CUBE-SCH-001 | REV: 1.00

Date: 11/08/2014 21:20 | Sheet: 1/1

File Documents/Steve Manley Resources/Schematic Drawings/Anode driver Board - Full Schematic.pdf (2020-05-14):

IC2

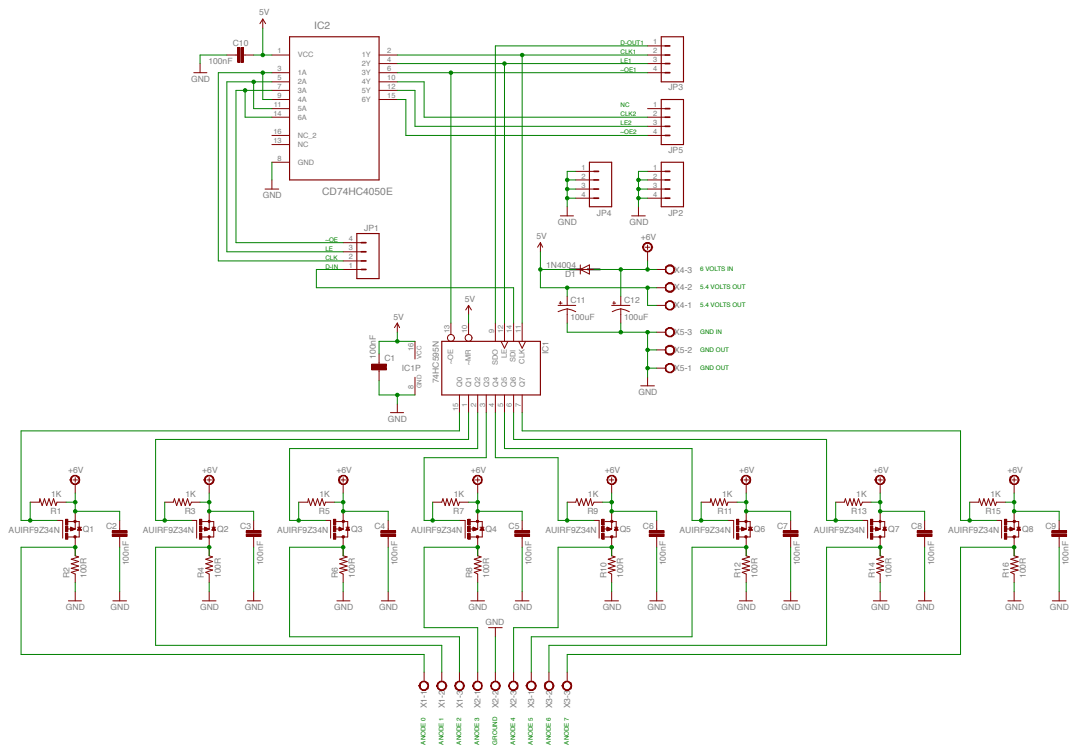
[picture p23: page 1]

NC 13 | | GND GND 5V
GND 8 | JP5

STEVE MANLEY:
3D 8x8x8 RGB LED CUBE PROJECT

Document Number: SJM-3D-8x8x8-RGB-LED-CUBE-SCH-003 | REV: 1.00

Date: 18/01/2015 18:23 | Sheet: 1/1

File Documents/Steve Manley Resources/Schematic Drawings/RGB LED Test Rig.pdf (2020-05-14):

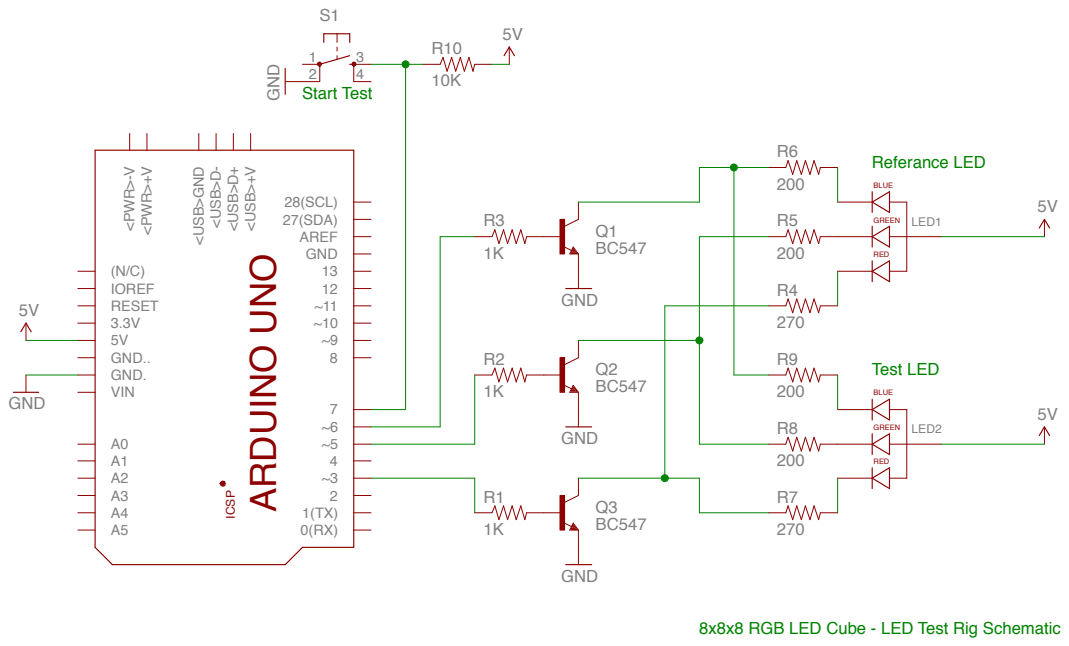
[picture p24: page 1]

8x8x8 RGB LED Cube - LED Test Rig Schematic

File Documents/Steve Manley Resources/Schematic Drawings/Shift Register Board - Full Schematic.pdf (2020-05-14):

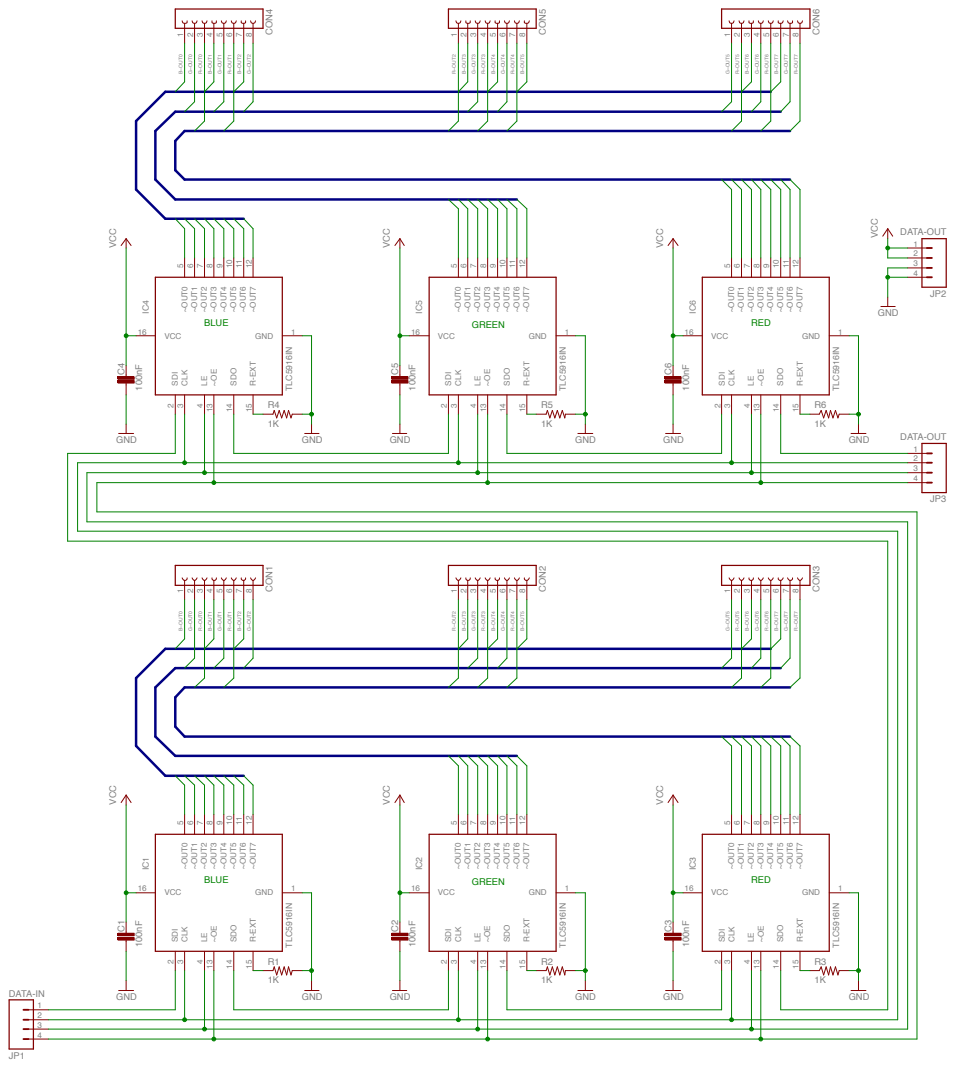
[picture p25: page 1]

STEVE MANLEY:
3D 8x8x8 RGB LED CUBE PROJECT

Document Number: SJM-3D-8x8x8-RGB-LED-CUBE-SCH-002 | REV: 1.00

Date: 16/08/2014 09:01 | Sheet: 1/1

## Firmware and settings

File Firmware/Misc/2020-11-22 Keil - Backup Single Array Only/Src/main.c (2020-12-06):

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

/* Includes ------------------------------------------------------------------*/
#include "main.h"

/* USER CODE BEGIN Includes */
#define NUM_TLCS    12
//#include "usbd_cdc_if.h"
#include <string.h>
#include <stdbool.h>
#include "lcd20x4_i2c.h"
#include "mpr121.h"
#include "tlc5940.h"
#include "Array8x8Functions.h"
#include "LyrFrameFunctions.h"
/* USER CODE END Includes */

I2C_HandleTypeDef hi2c1;

RTC_HandleTypeDef hrtc;

SPI_HandleTypeDef hspi1;

TIM_HandleTypeDef htim1;
TIM_HandleTypeDef htim2;

UART_HandleTypeDef huart1;

void SystemClock_Config(void);
static void MX_GPIO_Init(void);
static void MX_I2C1_Init(void);
static void MX_RTC_Init(void);
static void MX_SPI1_Init(void);
static void MX_TIM1_Init(void);
static void MX_TIM2_Init(void);
static void MX_USART1_UART_Init(void);
/* USER CODE BEGIN PFP */
void fade_in_color(LyrFrame_TypeDef lyrFrame, bool mask[64], uint64_t color, uint16_t maxBrightness, uint16_t deltaBrightness, uint16_t delay);
void fade_out_color(LyrFrame_TypeDef lyrFrame, bool mask[64], uint64_t color, uint16_t minBrightness, uint16_t deltaBrightness, uint16_t delay);
void fade_in_red(LyrFrame_TypeDef lyrFrame, bool mask[64], uint16_t maxBrightness, uint16_t deltaBrightness, uint16_t delay);
void fade_in_grn(LyrFrame_TypeDef lyrFrame, bool mask[64], uint16_t maxBrightness, uint16_t deltaBrightness, uint16_t delay);
void fade_in_blu(LyrFrame_TypeDef lyrFrame, bool mask[64], uint16_t maxBrightness, uint16_t deltaBrightness, uint16_t delay);
void fade_out_red(LyrFrame_TypeDef lyrFrame, bool mask[64], uint16_t minBrightness, uint16_t deltaBrightness, uint16_t delay);
void fade_out_grn(LyrFrame_TypeDef lyrFrame, bool mask[64], uint16_t minBrightness, uint16_t deltaBrightness, uint16_t delay);
void fade_out_blu(LyrFrame_TypeDef lyrFrame, bool mask[64], uint16_t minBrightness, uint16_t deltaBrightness, uint16_t delay);
void previous_lyr_off(uint16_t activeLyr);
uint16_t current_lyr_on(uint16_t activeLyr);
/* USER CODE END PFP */

/* USER CODE BEGIN 0 */

bool MAIN_MENU_ENABLED = 1;	
bool PIN_MAPPING_ENABLED = 0;
bool APPLICATION_ENABLED = 0;
bool KEYPAD_IRQ = 0; //when this is set, indicates that the keypad must be read
bool DONT_BLANK = 0;
bool UPDATE_FRAME = 0;

Frame_TypeDef frame0;

//lyr global variable indicates active cube layer.
//Needs to be global so timer IRQ can access value
uint8_t activeLyr = 0;

//Data Arrays & Pointers shese should probably not be global
// Data Arrays
uint16_t data16[16*NUM_TLCS];
uint8_t data8[24*NUM_TLCS];

// Data Pointers
uint16_t *data16Ptr = &data16[0];
uint8_t *data8Ptr = &data8[0];

// Needs to be global for convenient timer IRQ access
uint8_t initNumPM = 0;
uint16_t initValPM = 0;
uint16_t stepSizePM = 500;
uint16_t minValPM = 0;
uint16_t maxValPM = 4000;

uint16_t ledNumPM;
int16_t redValPM;
int16_t bluValPM;
int16_t grnValPM;

//Color Definition Begin
uint64_t null =				0x000000000000;
uint64_t red = 				0x0fff00000000;
uint64_t yellow = 		0x0fff0fff0000;
uint64_t green = 			0x00000fff0000;
uint64_t cyan = 			0x00000fff0fff;
uint64_t blue = 			0x000000000fff;
uint64_t purple = 		0x0fff00000fff;
uint64_t white = 			0x0fff0fff0fff;

uint64_t orange = 		0x0fff08000000;
uint64_t yelgrn = 		0x08000fff0000;
uint64_t seafoam = 		0x00000fff0800;
uint64_t lightblu = 	0x000008000fff;
uint64_t indigo = 		0x080000000fff;
uint64_t pink = 			0x0fff00000800;

uint64_t whiteRed = 	0x0fff08000800;
uint64_t whiteGrn = 	0x08000fff0800;
uint64_t whiteBlu = 	0x080008000fff;

//Color Definition End

// This is how I'm manually specifying layer patterns for now!
bool mask0[64] = {1,1,1,1,1,1,1,1,
									1,0,0,0,0,0,0,1,
									1,0,0,0,0,0,0,1,
									1,0,0,0,0,0,0,1,
									1,0,0,0,0,0,0,1,
									1,0,0,0,0,0,0,1,
									1,0,0,0,0,0,0,1,
									1,1,1,1,1,1,1,1};

bool mask1[64] = {0,0,0,0,0,0,0,0,
									0,1,1,1,1,1,1,0,
									0,1,0,0,0,0,1,0,
									0,1,0,0,0,0,1,0,
									0,1,0,0,0,0,1,0,
									0,1,0,0,0,0,1,0,
									0,1,1,1,1,1,1,0,
									0,0,0,0,0,0,0,0};

bool mask2[64] = {0,0,0,0,0,0,0,0,
									0,0,0,0,0,0,0,0,
									0,0,1,1,1,1,0,0,
									0,0,1,0,0,1,0,0,
									0,0,1,0,0,1,0,0,
									0,0,1,1,1,1,0,0,
									0,0,0,0,0,0,0,0,
									0,0,0,0,0,0,0,0};

bool mask3[64] = {0,0,0,0,0,0,0,0,
									0,0,0,0,0,0,0,0,
									0,0,0,0,0,0,0,0,
									0,0,0,1,1,0,0,0,
									0,0,0,1,1,0,0,0,
									0,0,0,0,0,0,0,0,
									0,0,0,0,0,0,0,0,
									0,0,0,0,0,0,0,0};

bool mask4[64] = {1,1,1,1,1,1,1,1,
									1,0,0,0,0,0,0,1,
									1,0,1,1,1,1,0,1,
									1,0,1,0,0,1,0,1,
									1,0,1,0,0,1,0,1,
									1,0,1,1,1,1,0,1,
									1,0,0,0,0,0,0,1,
									1,1,1,1,1,1,1,1};

bool mask5[64] = {1,1,1,1,1,1,1,1,
									1,1,0,0,0,0,1,1,
									1,0,1,0,0,1,0,1,
									1,0,0,1,1,0,0,1,
									1,0,0,1,1,0,0,1,
									1,0,1,0,0,1,0,1,
									1,1,0,0,0,0,1,1,
									1,1,1,1,1,1,1,1};

bool mask6[64] = {0,0,0,0,0,0,0,0,
									1,1,1,1,1,1,1,1,
									0,0,0,0,0,0,0,0,
									1,1,1,1,1,1,1,1,
									0,0,0,0,0,0,0,1,
									1,1,1,1,1,1,1,1,
									0,0,0,0,0,0,0,0,
									1,1,1,1,1,1,1,1};

bool mask7[64] = {1,1,1,1,1,1,1,1,
									0,0,0,0,0,0,0,0,
									1,1,1,1,1,1,1,1,
									0,0,0,0,0,0,0,0,
									1,1,1,1,1,1,1,1,
									0,0,0,0,0,0,0,0,
									1,1,1,1,1,1,1,1,
									0,0,0,0,0,0,0,0};

bool maskAll[64] = {1,1,1,1,1,1,1,1,
									  1,1,1,1,1,1,1,1,
									  1,1,1,1,1,1,1,1,
									  1,1,1,1,1,1,1,1,
									  1,1,1,1,1,1,1,1,
									  1,1,1,1,1,1,1,1,
									  1,1,1,1,1,1,1,1,
									  1,1,1,1,1,1,1,1};									

bool *mask0Ptr = &mask0[0];
bool *mask1Ptr = &mask1[0];
bool *mask2Ptr = &mask2[0];
bool *mask3Ptr = &mask3[0];
bool *mask4Ptr = &mask4[0];
bool *mask5Ptr = &mask5[0];
bool *mask6Ptr = &mask6[0];
bool *mask7Ptr = &mask7[0];
										
// pin mapping - this should never need to be reconfigured now that all the cabling as been eliminated :^)
int redMap[64] = {178,181,160,163,166,145,148,151,189,186,175,172,169,158,155,152,130,133,112,115,118,97,100,103,141,138,127,124,121,110,107,104,82,85,64,67,70,49,52,55,93,90,79,76,73,62,59,56,34,37,16,19,22,1,4,7,45,42,31,28,25,14,11,8};
int grnMap[64] = {177,180,183,162,165,144,147,150,190,187,184,173,170,159,156,153,129,132,135,114,117,96,99,102,142,139,136,125,122,111,108,105,81,84,87,66,69,48,51,54,94,91,88,77,74,63,60,57,33,36,39,18,21,0,3,6,46,43,40,29,26,15,12,9};
int bluMap[64] = {176,179,182,161,164,167,146,149,191,188,185,174,171,168,157,154,128,131,134,113,116,119,98,101,143,140,137,126,123,120,109,106,80,83,86,65,68,71,50,53,95,92,89,78,75,72,61,58,32,35,38,17,20,23,2,5,47,44,41,30,27,24,13,10};
	
/* USER CODE END 0 */

/**
  * @brief  The application entry point.
  * @retval int
  */
int main(void)
{
  /* MCU Configuration--------------------------------------------------------*/

  /* Reset of all peripherals, Initializes the Flash interface and the Systick. */
  HAL_Init();

  /* Configure the system clock */
  SystemClock_Config();

  /* Initialize all configured peripherals */
  MX_GPIO_Init();
  MX_I2C1_Init();
  MX_RTC_Init();
  MX_SPI1_Init();
  MX_TIM1_Init();
  MX_TIM2_Init();
  MX_USART1_UART_Init();
  /* USER CODE BEGIN 2 */
	
	//have to manually set the pointers
	frame0.lyr0.redArrPtr = &frame0.lyr0.redArray[0];
	frame0.lyr0.grnArrPtr = &frame0.lyr0.grnArray[0];
	frame0.lyr0.bluArrPtr = &frame0.lyr0.bluArray[0];
	
	// This pin referencing is slightly redundant. L8 needs to be set since it's toggled during timXocstart (158)
	HAL_GPIO_WritePin(L8_EN_GPIO_Port, L8_EN_Pin, GPIO_PIN_RESET);
	HAL_GPIO_WritePin(L7_EN_GPIO_Port, L7_EN_Pin, GPIO_PIN_RESET);
	HAL_GPIO_WritePin(L6_EN_GPIO_Port, L6_EN_Pin, GPIO_PIN_RESET);
	HAL_GPIO_WritePin(L5_EN_GPIO_Port, L5_EN_Pin, GPIO_PIN_RESET);
	HAL_GPIO_WritePin(L4_EN_GPIO_Port, L4_EN_Pin, GPIO_PIN_RESET);
	HAL_GPIO_WritePin(L3_EN_GPIO_Port, L3_EN_Pin, GPIO_PIN_RESET);
	HAL_GPIO_WritePin(L2_EN_GPIO_Port, L2_EN_Pin, GPIO_PIN_RESET);
	HAL_GPIO_WritePin(L1_EN_GPIO_Port, L1_EN_Pin, GPIO_PIN_RESET);


	HAL_TIM_OC_Start(&htim2, TIM_CHANNEL_2);	//
	HAL_TIM_Base_Start_IT(&htim1);
	HAL_TIM_OC_Start(&htim1, TIM_CHANNEL_4);	//this was working with ch1 even though thats set as a gpio!

	// LCD & MPR121 INIT BEGIN
	lcd20x4_i2c_init(&hi2c1);
	HAL_Delay(100);
	mpr121_init(&hi2c1, (KEYPAD_ADDRESS<<1), &hi2c1);	
	HAL_Delay(100);
	mpr121_init(&hi2c1, (WHEEL_ADDRESS<<1), &hi2c1);
	HAL_Delay(100);
	lcd20x4_i2c_clear();
	HAL_Delay(100);	
	
	if(HAL_I2C_IsDeviceReady(&hi2c1, (KEYPAD_ADDRESS<<1), 2, 10) == HAL_OK)
		{
			lcd20x4_i2c_1stLine();
			HAL_Delay(50);
			lcd20x4_i2c_printf("Keypad Ready!");
		}
	else lcd20x4_i2c_printf("Keypad Init Failed");
	lcd20x4_i2c_2ndLine();	
		
	
	if(HAL_I2C_IsDeviceReady(&hi2c1, (WHEEL_ADDRESS<<1), 2, 10) == HAL_OK)
		{
			HAL_Delay(50);
			lcd20x4_i2c_printf("Wheel Ready!");
		}
	else lcd20x4_i2c_printf("Wheel Init Failed");
	lcd20x4_i2c_1stLine();
		
		
	HAL_Delay(1000);
	lcd20x4_i2c_clear();
		
	HAL_GPIO_WritePin(L8_EN_GPIO_Port, L8_EN_Pin, GPIO_PIN_SET);	
	
	//LCD & MPR121 INIT END
	
	HAL_SPI_Init(&hspi1);

  /* USER CODE END 2 */

  /* Infinite loop */
  /* USER CODE BEGIN WHILE */
  while (1)
  {
    
		if(MAIN_MENU_ENABLED == 1)
		{
			
			tlc_clear(data16Ptr);
			tlc_update(hspi1,data16Ptr,data8Ptr);
			lcd20x4_i2c_clear();
			lcd20x4_i2c_1stLine();
			lcd20x4_i2c_printf("Main Menu");
			lcd20x4_i2c_2ndLine();
			lcd20x4_i2c_printf("1 - Application");
			lcd20x4_i2c_3rdLine();
			lcd20x4_i2c_printf("2 - Pin Mapping");	
			
			while(MAIN_MENU_ENABLED == 1)
			{
				HAL_Delay(50);
			}
		}
		
		if(APPLICATION_ENABLED == 1)
		{
			lcd20x4_i2c_clear();
			lcd20x4_i2c_1stLine();
			lcd20x4_i2c_printf("Press 3 to go back");
						

			while(APPLICATION_ENABLED == 1)
			{
				
				uint16_t maxBrightness = 4000;
				uint16_t minBrightness = 0;
				uint16_t deltaBrightness = 100;
				uint16_t delay = 10;
				
				
				uint64_t colorWheel[12] = {red,orange,yellow,yelgrn,green,seafoam,cyan,lightblu,blue,indigo,purple,pink};	
				int caseNum = 0;
		
				while (caseNum<12)
				{
					fade_in_color(frame0.lyr0,mask0,colorWheel[caseNum],maxBrightness,deltaBrightness,delay);					
					fade_out_color(frame0.lyr0,mask0,colorWheel[caseNum],minBrightness,deltaBrightness,delay);
					HAL_Delay(500);
					caseNum++;
					
					fade_in_color(frame0.lyr0,mask1,colorWheel[caseNum],maxBrightness,deltaBrightness,delay);					
					fade_out_color(frame0.lyr0,mask1,colorWheel[caseNum],minBrightness,deltaBrightness,delay);
					HAL_Delay(500);
					caseNum++;
					
					fade_in_color(frame0.lyr0,mask2,colorWheel[caseNum],maxBrightness,deltaBrightness,delay);					
					fade_out_color(frame0.lyr0,mask2,colorWheel[caseNum],minBrightness,deltaBrightness,delay);
					HAL_Delay(500);
					caseNum++;
					
					fade_in_color(frame0.lyr0,mask3,colorWheel[caseNum],maxBrightness,deltaBrightness,delay);					
					fade_out_color(frame0.lyr0,mask3,colorWheel[caseNum],minBrightness,deltaBrightness,delay);
					HAL_Delay(500);
					caseNum++;
					
					fade_in_color(frame0.lyr0,mask2,colorWheel[caseNum],maxBrightness,deltaBrightness,delay);					
					fade_out_color(frame0.lyr0,mask2,colorWheel[caseNum],minBrightness,deltaBrightness,delay);
					HAL_Delay(500);
					caseNum++;
					
					fade_in_color(frame0.lyr0,mask1,colorWheel[caseNum],maxBrightness,deltaBrightness,delay);					
					fade_out_color(frame0.lyr0,mask1,colorWheel[caseNum],minBrightness,deltaBrightness,delay);
					HAL_Delay(500);
					caseNum++;
					
				}
				
				
			}
		}		
		
		
		if(PIN_MAPPING_ENABLED == 1)
		{
			lcd20x4_i2c_clear();
			lcd20x4_i2c_1stLine();
			lcd20x4_i2c_printf("LED # 123");
			lcd20x4_i2c_2ndLine();
			lcd20x4_i2c_printf("RED: 255");
			lcd20x4_i2c_3rdLine();
			lcd20x4_i2c_printf("GRN: 255");
			lcd20x4_i2c_4thLine();
			lcd20x4_i2c_printf("BLU: 255");
			
			ledNumPM = initNumPM;
			redValPM = initValPM;
			bluValPM = initValPM;
			grnValPM = initValPM;

			
			while(PIN_MAPPING_ENABLED == 1)
			{
				tlc_clear(data16Ptr);
				tlc_set_led(data16Ptr,redMap[ledNumPM],redValPM);
				tlc_set_led(data16Ptr,grnMap[ledNumPM],grnValPM);
				tlc_set_led(data16Ptr,bluMap[ledNumPM],bluValPM);
				tlc_update(hspi1, data16Ptr,data8Ptr);
				
				lcd20x4_i2c_clear();
				lcd20x4_i2c_1stLine();
				lcd20x4_i2c_printf("LED # %d", ledNumPM);
				lcd20x4_i2c_2ndLine();
				lcd20x4_i2c_printf("RED: %d", redValPM);
				lcd20x4_i2c_3rdLine();
				lcd20x4_i2c_printf("GRN: %d", grnValPM);
				lcd20x4_i2c_4thLine();
				lcd20x4_i2c_printf("BLU: %d", bluValPM);				

			}
		}
	}
}		
		
    /* USER CODE END WHILE */

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
/* USER CODE BEGIN 4 */
void HAL_GPIO_EXTI_Callback(uint16_t GPIO_Pin)
{
	KEYPAD_IRQ = 0;
	
	//ensures that MPR121s aren't read while LCD is being written to
	I2C_HandleTypeDef *phi2c1 = &hi2c1;
	if (phi2c1->State != HAL_I2C_STATE_READY)
	{
		KEYPAD_IRQ = 1;
		return;
	}
	
	uint8_t keypadVal;	
	

	keypadVal = mpr121_keyPad(&hi2c1, (KEYPAD_ADDRESS<<1));
	HAL_Delay(50);
	if(GPIO_Pin == Keypad_IRQ_Pin)
	{
		if(MAIN_MENU_ENABLED == true)
		{
			if(keypadVal == 1)
			{
				APPLICATION_ENABLED = true;
				MAIN_MENU_ENABLED = false;
				return;
			}
			
			if(keypadVal == 2)
			{
				PIN_MAPPING_ENABLED = true;
				MAIN_MENU_ENABLED = false;
				return;
			}
			return;
		}
		
		if(APPLICATION_ENABLED == true)
		{
			if(keypadVal == 3)
			{
				//MAIN_MENU_ENABLED = true;
				//APPLICATION_ENABLED = false;
				return;
			}
			return;
		}

		if(PIN_MAPPING_ENABLED == true)
		{
			if(keypadVal == 1)
				redValPM=redValPM + stepSizePM;
				if (redValPM > maxValPM) redValPM = 0;
			if(keypadVal == 2)
				bluValPM=grnValPM + stepSizePM;
				if (bluValPM > maxValPM) bluValPM = 0;
			if(keypadVal == 3)
				grnValPM=bluValPM + stepSizePM;
				if (grnValPM > maxValPM) grnValPM = 0;
			if(keypadVal == 4)
			{
				if (ledNumPM==0) ledNumPM = 64;
				ledNumPM--;
			}
			if(keypadVal == 6)
			{
				ledNumPM++;
				if (ledNumPM==64) ledNumPM = 0;
			}
			if(keypadVal == 7)
				redValPM=redValPM - stepSizePM;
				if (redValPM < minValPM) redValPM = maxValPM;
			if(keypadVal == 8)
				grnValPM=grnValPM - stepSizePM;
				if (grnValPM < minValPM) grnValPM = maxValPM;
			if(keypadVal == 9)
				bluValPM=bluValPM - stepSizePM;
				if (bluValPM < minValPM) bluValPM = maxValPM;
			if(keypadVal == 10)
			{
				MAIN_MENU_ENABLED = true;
				PIN_MAPPING_ENABLED = false;
				return;
			}
			return;
		}
	}
}

void HAL_TIM_PeriodElapsedCallback(TIM_HandleTypeDef *htim)
{	
	if(UPDATE_FRAME==0)
	{
		previous_lyr_off(activeLyr);
		HAL_GPIO_WritePin(BLANK_3V3_GPIO_Port, BLANK_3V3_Pin, GPIO_PIN_SET);
		for(uint16_t dummyVar =1;dummyVar<15;dummyVar++); // short delay (approx 3us)
		HAL_GPIO_WritePin(BLANK_3V3_GPIO_Port, BLANK_3V3_Pin, GPIO_PIN_RESET);
		activeLyr =  current_lyr_on(activeLyr);
		return;
	}
	
	if(UPDATE_FRAME==1)
	{
		previous_lyr_off(activeLyr);
		tlc_spi_convert(data16Ptr, data8Ptr);
		HAL_SPI_Transmit(&hspi1, data8Ptr, 24*NUM_TLCS, 10);
		HAL_GPIO_WritePin(BLANK_3V3_GPIO_Port, BLANK_3V3_Pin, GPIO_PIN_SET);
		HAL_GPIO_WritePin(XLAT_3V3_GPIO_Port, XLAT_3V3_Pin, GPIO_PIN_SET);
		for(uint16_t dummyVar =1;dummyVar<15;dummyVar++); // short delay (approx 3us)
		HAL_GPIO_WritePin(XLAT_3V3_GPIO_Port, XLAT_3V3_Pin, GPIO_PIN_RESET);
		HAL_GPIO_WritePin(BLANK_3V3_GPIO_Port, BLANK_3V3_Pin, GPIO_PIN_RESET);
		UPDATE_FRAME=0;
		activeLyr =  current_lyr_on(activeLyr);
		return;
	}
}
	
	
	//I think blank should be toggled in this callback for improved synchronization
	/*
	if(activeLyr==0)
	{
		HAL_GPIO_TogglePin(L8_EN_GPIO_Port, L8_EN_Pin); //turn off previous layer
		tlc_clear(data16Ptr);
		tlc_set_lyr(data16Ptr,seafoam,mask5);
		tlc_update(data16Ptr,data8Ptr);
		HAL_GPIO_TogglePin(L1_EN_GPIO_Port, L1_EN_Pin);	//turn on current layer
	}

	if(activeLyr==1){
		HAL_GPIO_TogglePin(L1_EN_GPIO_Port, L1_EN_Pin);
		tlc_clear(data16Ptr);
		tlc_set_lyr(data16Ptr,red,mask5);
		tlc_update(data16Ptr,data8Ptr);
		HAL_GPIO_TogglePin(L2_EN_GPIO_Port, L2_EN_Pin);}

	if(activeLyr==2){
		HAL_GPIO_TogglePin(L2_EN_GPIO_Port, L2_EN_Pin);
		tlc_clear(data16Ptr);
		tlc_set_lyr(data16Ptr,cyan,mask5);
		tlc_update(data16Ptr,data8Ptr);
		HAL_GPIO_TogglePin(L3_EN_GPIO_Port, L3_EN_Pin);}

	if(activeLyr==3){
		HAL_GPIO_TogglePin(L3_EN_GPIO_Port, L3_EN_Pin);
		tlc_clear(data16Ptr);
		tlc_set_lyr(data16Ptr,purple,mask5);
		tlc_update(data16Ptr,data8Ptr);
		HAL_GPIO_TogglePin(L4_EN_GPIO_Port, L4_EN_Pin);}

	if(activeLyr==4){
		HAL_GPIO_TogglePin(L4_EN_GPIO_Port, L4_EN_Pin);
		tlc_clear(data16Ptr);
		tlc_set_lyr(data16Ptr,pink,mask5);
		tlc_update(data16Ptr,data8Ptr);
		HAL_GPIO_TogglePin(L5_EN_GPIO_Port, L5_EN_Pin);}

	if(activeLyr==5){
		HAL_GPIO_TogglePin(L5_EN_GPIO_Port, L5_EN_Pin);
		tlc_clear(data16Ptr);
		tlc_set_lyr(data16Ptr,frameColor,mask5);
		tlc_update(data16Ptr,data8Ptr);
		HAL_GPIO_TogglePin(L6_EN_GPIO_Port, L6_EN_Pin);}

	if(activeLyr==6){
		HAL_GPIO_TogglePin(L6_EN_GPIO_Port, L6_EN_Pin);
		tlc_clear(data16Ptr);
		tlc_set_lyr(data16Ptr,blue,mask5);
		tlc_update(data16Ptr,data8Ptr);
		HAL_GPIO_TogglePin(L7_EN_GPIO_Port, L7_EN_Pin);}

	if(activeLyr==7){
		HAL_GPIO_TogglePin(L7_EN_GPIO_Port, L7_EN_Pin);
		tlc_clear(data16Ptr);
		tlc_set_lyr(data16Ptr,green,mask5);
		tlc_update(data16Ptr,data8Ptr);
		HAL_GPIO_TogglePin(L8_EN_GPIO_Port, L8_EN_Pin);}

	
	if(activeLyr==8) activeLyr = 0;
	*/
	
void previous_lyr_off(uint16_t activeLyr)
{
	if(activeLyr == 0) HAL_GPIO_TogglePin(L8_EN_GPIO_Port, L8_EN_Pin);
	if(activeLyr == 1) HAL_GPIO_TogglePin(L1_EN_GPIO_Port, L1_EN_Pin);
	if(activeLyr == 2) HAL_GPIO_TogglePin(L2_EN_GPIO_Port, L2_EN_Pin);
	if(activeLyr == 3) HAL_GPIO_TogglePin(L3_EN_GPIO_Port, L3_EN_Pin);
	if(activeLyr == 4) HAL_GPIO_TogglePin(L4_EN_GPIO_Port, L4_EN_Pin);
	if(activeLyr == 5) HAL_GPIO_TogglePin(L5_EN_GPIO_Port, L5_EN_Pin);
	if(activeLyr == 6) HAL_GPIO_TogglePin(L6_EN_GPIO_Port, L6_EN_Pin);
	if(activeLyr == 7) HAL_GPIO_TogglePin(L7_EN_GPIO_Port, L7_EN_Pin);
}
	
uint16_t current_lyr_on(uint16_t activeLyr)
{
	if(activeLyr == 0) HAL_GPIO_TogglePin(L1_EN_GPIO_Port, L1_EN_Pin);
	if(activeLyr == 1) HAL_GPIO_TogglePin(L2_EN_GPIO_Port, L2_EN_Pin);
	if(activeLyr == 2) HAL_GPIO_TogglePin(L3_EN_GPIO_Port, L3_EN_Pin);
	if(activeLyr == 3) HAL_GPIO_TogglePin(L4_EN_GPIO_Port, L4_EN_Pin);
	if(activeLyr == 4) HAL_GPIO_TogglePin(L5_EN_GPIO_Port, L5_EN_Pin);
	if(activeLyr == 5) HAL_GPIO_TogglePin(L6_EN_GPIO_Port, L6_EN_Pin);
	if(activeLyr == 6) HAL_GPIO_TogglePin(L7_EN_GPIO_Port, L7_EN_Pin);
	if(activeLyr == 7) HAL_GPIO_TogglePin(L8_EN_GPIO_Port, L8_EN_Pin);
	activeLyr++;
	if(activeLyr==8) activeLyr = 0;
	return activeLyr;
}

	
//void CDC_ReceiveCallBack(uint8_t *buf, uint32_t len){
//	CDC_Transmit_FS(buf, len);
//}

void fade_in_color(LyrFrame_TypeDef lyrFrame, bool mask[64], uint64_t color, uint16_t maxBrightness, uint16_t deltaBrightness, uint16_t delay)
{
	int16_t redBrightness = (color>>32);
	int16_t grnBrightness = (color>>16);
	int16_t bluBrightness = (color>>0);
	int16_t redDeltaBrightness = 0x0000;
	int16_t grnDeltaBrightness = 0x0000;
	int16_t bluDeltaBrightness = 0x0000;
	int16_t currentBrightness = 0; //hopefully since its signed there's no negative number hard fault.
	
	if (redBrightness >= 4000)
	{
		redBrightness = 0;
		redDeltaBrightness = deltaBrightness;
	}
	
	if ((redBrightness < 4000) & (redBrightness > 0)) 
	{
		redBrightness = 0;
		redDeltaBrightness = (deltaBrightness/2);
	}
	
	
	if (grnBrightness >= 4000)
	{
		grnBrightness = 0;
		grnDeltaBrightness = deltaBrightness;
	}
	
	if ((grnBrightness < 4000) & (grnBrightness > 0)) 
	{
		grnBrightness = 0;
		grnDeltaBrightness = (deltaBrightness/2);
	}	
	
	if (bluBrightness >= 4000)
	{
		bluBrightness = 0;
		bluDeltaBrightness = deltaBrightness;
	}
	
	if ((bluBrightness < 4000) & (bluBrightness > 0)) 
	{
		bluBrightness = 0;
		bluDeltaBrightness = (deltaBrightness/2);
	}
	
	while (currentBrightness <= maxBrightness)
	{
		lyr_frame_set_single_rgb(lyrFrame.redArrPtr, redBrightness, mask);
		lyr_frame_set_single_rgb(lyrFrame.grnArrPtr, grnBrightness, mask);
		lyr_frame_set_single_rgb(lyrFrame.bluArrPtr, bluBrightness, mask);
		lyr_frame_convert(frame0.lyr0,data16Ptr);
		UPDATE_FRAME=1;
		HAL_Delay(delay);
		if(currentBrightness==4000) HAL_Delay(1);
		currentBrightness = currentBrightness + deltaBrightness;
		redBrightness = redBrightness + redDeltaBrightness;
		grnBrightness = grnBrightness + grnDeltaBrightness;
		bluBrightness = bluBrightness + bluDeltaBrightness;
	}
}
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

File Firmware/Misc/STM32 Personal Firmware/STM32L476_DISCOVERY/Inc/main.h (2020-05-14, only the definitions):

#define SAI1_MCK_Pin GPIO_PIN_2
#define SAI1_MCK_GPIO_Port GPIOE
#define AUDIO_RST_Pin GPIO_PIN_3
#define AUDIO_RST_GPIO_Port GPIOE
#define SAI1_FS_Pin GPIO_PIN_4
#define SAI1_FS_GPIO_Port GPIOE
#define SAI1_SCK_Pin GPIO_PIN_5
#define SAI1_SCK_GPIO_Port GPIOE
#define SAI1_SD_Pin GPIO_PIN_6
#define SAI1_SD_GPIO_Port GPIOE
#define MFX_IRQ_OUT_Pin GPIO_PIN_13
#define MFX_IRQ_OUT_GPIO_Port GPIOC
#define MAG_INT_Pin GPIO_PIN_1
#define MAG_INT_GPIO_Port GPIOC
#define MAG_DRDY_Pin GPIO_PIN_2
#define MAG_DRDY_GPIO_Port GPIOC
#define VLCD_Pin GPIO_PIN_3
#define VLCD_GPIO_Port GPIOC
#define JOY_CENTER_Pin GPIO_PIN_0
#define JOY_CENTER_GPIO_Port GPIOA
#define JOY_LEFT_Pin GPIO_PIN_1
#define JOY_LEFT_GPIO_Port GPIOA
#define JOY_RIGHT_Pin GPIO_PIN_2
#define JOY_RIGHT_GPIO_Port GPIOA
#define JOY_UP_Pin GPIO_PIN_3
#define JOY_UP_GPIO_Port GPIOA
#define MFX_WAKEUP_Pin GPIO_PIN_4
#define MFX_WAKEUP_GPIO_Port GPIOA
#define JOY_DOWN_Pin GPIO_PIN_5
#define JOY_DOWN_GPIO_Port GPIOA
#define SEG23_Pin GPIO_PIN_6
#define SEG23_GPIO_Port GPIOA
#define SEG0_Pin GPIO_PIN_7
#define SEG0_GPIO_Port GPIOA
#define SEG22_Pin GPIO_PIN_4
#define SEG22_GPIO_Port GPIOC
#define SEG1_Pin GPIO_PIN_5
#define SEG1_GPIO_Port GPIOC
#define SEG21_Pin GPIO_PIN_0
#define SEG21_GPIO_Port GPIOB
#define SEG2_Pin GPIO_PIN_1
#define SEG2_GPIO_Port GPIOB
#define LD_R_Pin GPIO_PIN_2
#define LD_R_GPIO_Port GPIOB
#define AUDIO_DIN_Pin GPIO_PIN_7
#define AUDIO_DIN_GPIO_Port GPIOE
#define LD_G_Pin GPIO_PIN_8
#define LD_G_GPIO_Port GPIOE
#define AUDIO_CLK_Pin GPIO_PIN_9
#define AUDIO_CLK_GPIO_Port GPIOE
#define QSPI_CLK_Pin GPIO_PIN_10
#define QSPI_CLK_GPIO_Port GPIOE
#define QSPI_CS_Pin GPIO_PIN_11
#define QSPI_CS_GPIO_Port GPIOE
#define QSPI_D0_Pin GPIO_PIN_12
#define QSPI_D0_GPIO_Port GPIOE
#define QSPI_D1_Pin GPIO_PIN_13
#define QSPI_D1_GPIO_Port GPIOE
#define QSPI_D2_Pin GPIO_PIN_14
#define QSPI_D2_GPIO_Port GPIOE
#define QSPI_D3_Pin GPIO_PIN_15
#define QSPI_D3_GPIO_Port GPIOE
#define MFX_I2C_SLC_Pin GPIO_PIN_10
#define MFX_I2C_SLC_GPIO_Port GPIOB
#define MFX_I2C_SDA_Pin GPIO_PIN_11
#define MFX_I2C_SDA_GPIO_Port GPIOB
#define SEG20_Pin GPIO_PIN_12
#define SEG20_GPIO_Port GPIOB
#define SEG3_Pin GPIO_PIN_13
#define SEG3_GPIO_Port GPIOB
#define SEG19_Pin GPIO_PIN_14
#define SEG19_GPIO_Port GPIOB
#define SEG4_Pin GPIO_PIN_15
#define SEG4_GPIO_Port GPIOB
#define SEG18_Pin GPIO_PIN_8
#define SEG18_GPIO_Port GPIOD
#define SEG5_Pin GPIO_PIN_9
#define SEG5_GPIO_Port GPIOD
#define SEG17_Pin GPIO_PIN_10
#define SEG17_GPIO_Port GPIOD
#define SEG6_Pin GPIO_PIN_11
#define SEG6_GPIO_Port GPIOD
#define SEG16_Pin GPIO_PIN_12
#define SEG16_GPIO_Port GPIOD
#define SEG7_Pin GPIO_PIN_13
#define SEG7_GPIO_Port GPIOD
#define SEG15_Pin GPIO_PIN_14
#define SEG15_GPIO_Port GPIOD
#define SEG8_Pin GPIO_PIN_15
#define SEG8_GPIO_Port GPIOD
#define SEG14_Pin GPIO_PIN_6
#define SEG14_GPIO_Port GPIOC
#define SEG9_Pin GPIO_PIN_7
#define SEG9_GPIO_Port GPIOC
#define SEG13_Pin GPIO_PIN_8
#define SEG13_GPIO_Port GPIOC
#define OTG_FS_PowerSwitchOn_Pin GPIO_PIN_9
#define OTG_FS_PowerSwitchOn_GPIO_Port GPIOC
#define COM0_Pin GPIO_PIN_8
#define COM0_GPIO_Port GPIOA
#define COM1_Pin GPIO_PIN_9
#define COM1_GPIO_Port GPIOA
#define COM2_Pin GPIO_PIN_10
#define COM2_GPIO_Port GPIOA
#define OTG_FS_DM_Pin GPIO_PIN_11
#define OTG_FS_DM_GPIO_Port GPIOA
#define OTG_FS_DP_Pin GPIO_PIN_12
#define OTG_FS_DP_GPIO_Port GPIOA
#define SWDIO_Pin GPIO_PIN_13
#define SWDIO_GPIO_Port GPIOA
#define SWCLK_Pin GPIO_PIN_14
#define SWCLK_GPIO_Port GPIOA
#define SEG10_Pin GPIO_PIN_15
#define SEG10_GPIO_Port GPIOA
#define OTG_FS_OverCurrent_Pin GPIO_PIN_10
#define OTG_FS_OverCurrent_GPIO_Port GPIOC
#define OTG_FS_VBUS_Pin GPIO_PIN_11
#define OTG_FS_VBUS_GPIO_Port GPIOC
#define EXT_RST_Pin GPIO_PIN_0
#define EXT_RST_GPIO_Port GPIOD
#define MEMS_SCK_Pin GPIO_PIN_1
#define MEMS_SCK_GPIO_Port GPIOD
#define GYRO_INT1_Pin GPIO_PIN_2
#define GYRO_INT1_GPIO_Port GPIOD
#define MEMS_MISO_Pin GPIO_PIN_3
#define MEMS_MISO_GPIO_Port GPIOD
#define MEMS_MOSI_Pin GPIO_PIN_4
#define MEMS_MOSI_GPIO_Port GPIOD
#define USART_TX_Pin GPIO_PIN_5
#define USART_TX_GPIO_Port GPIOD
#define USART_RX_Pin GPIO_PIN_6
#define USART_RX_GPIO_Port GPIOD
#define GYRO_CS_Pin GPIO_PIN_7
#define GYRO_CS_GPIO_Port GPIOD
#define M3V3_REG_ON_Pin GPIO_PIN_3
#define M3V3_REG_ON_GPIO_Port GPIOB
#define SEG11_Pin GPIO_PIN_4
#define SEG11_GPIO_Port GPIOB
#define SEG12_Pin GPIO_PIN_5
#define SEG12_GPIO_Port GPIOB
#define I2C1_SCL_Pin GPIO_PIN_6
#define I2C1_SCL_GPIO_Port GPIOB
#define I2C1_SDA_Pin GPIO_PIN_7
#define I2C1_SDA_GPIO_Port GPIOB
#define GYRO_INT2_Pin GPIO_PIN_8
#define GYRO_INT2_GPIO_Port GPIOB
#define COM3_Pin GPIO_PIN_9
#define COM3_GPIO_Port GPIOB
#define XL_CS_Pin GPIO_PIN_0
#define XL_CS_GPIO_Port GPIOE
#define XL_INT_Pin GPIO_PIN_1
#define XL_INT_GPIO_Port GPIOE

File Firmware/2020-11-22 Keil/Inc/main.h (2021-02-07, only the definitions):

#define GSCK_3V3_Pin GPIO_PIN_1
#define GSCK_3V3_GPIO_Port GPIOA
#define XLAT_3V3_Pin GPIO_PIN_4
#define XLAT_3V3_GPIO_Port GPIOA
#define SCLK_3V3_Pin GPIO_PIN_5
#define SCLK_3V3_GPIO_Port GPIOA
#define SOUT_3V3_Pin GPIO_PIN_6
#define SOUT_3V3_GPIO_Port GPIOA
#define SIN_3V3_Pin GPIO_PIN_7
#define SIN_3V3_GPIO_Port GPIOA
#define DCPRG_3V3_Pin GPIO_PIN_0
#define DCPRG_3V3_GPIO_Port GPIOB
#define VPRG_3V3_Pin GPIO_PIN_1
#define VPRG_3V3_GPIO_Port GPIOB
#define L3_EN_Pin GPIO_PIN_10
#define L3_EN_GPIO_Port GPIOB
#define L4_EN_Pin GPIO_PIN_11
#define L4_EN_GPIO_Port GPIOB
#define L5_EN_Pin GPIO_PIN_12
#define L5_EN_GPIO_Port GPIOB
#define L6_EN_Pin GPIO_PIN_13
#define L6_EN_GPIO_Port GPIOB
#define L7_EN_Pin GPIO_PIN_14
#define L7_EN_GPIO_Port GPIOB
#define L8_EN_Pin GPIO_PIN_15
#define L8_EN_GPIO_Port GPIOB
#define BLANK_3V3_Pin GPIO_PIN_8
#define BLANK_3V3_GPIO_Port GPIOA
#define ESP8266_RX_STM32_TX_Pin GPIO_PIN_9
#define ESP8266_RX_STM32_TX_GPIO_Port GPIOA
#define ESP8266_TX_STM32_RX_Pin GPIO_PIN_10
#define ESP8266_TX_STM32_RX_GPIO_Port GPIOA
#define ESP8266_EN_Pin GPIO_PIN_15
#define ESP8266_EN_GPIO_Port GPIOA
#define XERR_Pin GPIO_PIN_3
#define XERR_GPIO_Port GPIOB
#define Keypad_IRQ_Pin GPIO_PIN_4
#define Keypad_IRQ_GPIO_Port GPIOB
#define Keypad_IRQ_EXTI_IRQn EXTI4_IRQn
#define Wheel_IRQ_Pin GPIO_PIN_5
#define Wheel_IRQ_GPIO_Port GPIOB
#define Wheel_IRQ_EXTI_IRQn EXTI9_5_IRQn
#define L1_EN_Pin GPIO_PIN_8
#define L1_EN_GPIO_Port GPIOB
#define L2_EN_Pin GPIO_PIN_9
#define L2_EN_GPIO_Port GPIOB

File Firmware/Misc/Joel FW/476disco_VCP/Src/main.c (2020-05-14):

/**
  ******************************************************************************
  * @file           : main.c
  * @brief          : Main program body
  ******************************************************************************
  * This notice applies to any and all portions of this file
  * that are not between comment pairs USER CODE BEGIN and
  * USER CODE END. Other portions of this file, whether 
  * inserted by the user or by software development tools
  * are owned by their respective copyright owners.
  *
  * Copyright (c) 2019 STMicroelectronics International N.V. 
  * All rights reserved.
  *
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
  ******************************************************************************
  */
/* Includes ------------------------------------------------------------------*/
#include "main.h"
#include "stm32l4xx_hal.h"
#include "usb_device.h"

/* USER CODE BEGIN Includes */
#include "usbd_cdc_if.h"
#include <string.h>
/* USER CODE END Includes */

SPI_HandleTypeDef hspi1;

TIM_HandleTypeDef htim2;
TIM_HandleTypeDef htim5;

/* USER CODE BEGIN PV */

/* USER CODE END PV */

void SystemClock_Config(void);
static void MX_GPIO_Init(void);
static void MX_SPI1_Init(void);
static void MX_TIM2_Init(void);
static void MX_TIM5_Init(void);
                                    
void HAL_TIM_MspPostInit(TIM_HandleTypeDef *htim);
                                
                                

/* USER CODE BEGIN PFP */

/* USER CODE END PFP */

/**
  * @brief  The application entry point.
  *
  * @retval None
  */
int main(void)
{
  /* USER CODE BEGIN 1 */
	uint8_t myBuf[20] = "Hello World \r\n";
	uint8_t num = 0;
  /* USER CODE END 1 */

  /* MCU Configuration----------------------------------------------------------*/

  /* Reset of all peripherals, Initializes the Flash interface and the Systick. */
  HAL_Init();

  /* Configure the system clock */
  SystemClock_Config();

  /* Initialize all configured peripherals */
  MX_GPIO_Init();
  MX_SPI1_Init();
  MX_USB_DEVICE_Init();
  MX_TIM2_Init();
  MX_TIM5_Init();
	CDC_Transmit_FS(myBuf,strlen((char *)myBuf));
  /* Infinite loop */
  /* USER CODE BEGIN WHILE */
  while (1)
  {

  /* USER CODE END WHILE */

  /* USER CODE BEGIN 3 */
	CDC_Transmit_FS(myBuf,strlen((char *)myBuf));
	//printf("int value %i\r\n", num);
	num++;
	HAL_Delay(500);
  }
  /* USER CODE END 3 */

}

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
/* USER CODE BEGIN 4 */
void CDC_ReceiveCallBack(uint8_t *buf, uint32_t len){
	CDC_Transmit_FS(buf, len);
}

// inline function to swap two numbers
inline void swap(char *x, char *y) {
	char t = *x; *x = *y; *y = t;
}

// function to reverse buffer[i..j]
char* reverse(char *buffer, int i, int j)
{
	while (i < j)
		swap(&buffer[i++], &buffer[j--]);

	return buffer;
}

// Iterative function to implement itoa() function in C
char* itoa(int value, char* buffer, int base)
{
	// invalid input
	if (base < 2 || base > 32)
		return buffer;

	// consider absolute value of number
	int n = abs(value);

	int i = 0;
	while (n)
	{
		int r = n % base;

		if (r >= 10) 
			buffer[i++] = 65 + (r - 10);
		else
			buffer[i++] = 48 + r;

		n = n / base;
	}

	// if number is 0
	if (i == 0)
		buffer[i++] = '0';

	// If base is 10 and value is negative, the resulting string 
	// is preceded with a minus sign (-)
	// With any other base, value is always considered unsigned
	if (value < 0 && base == 10)
		buffer[i++] = '-';

	buffer[i] = '\0'; // null terminate string

	// reverse the string and return it
	return reverse(buffer, 0, i - 1);
}
/* USER CODE END 4 */
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


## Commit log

2019-02-25 Updated KiCAD schematic. TLC portion added.
    [STM32L486_LED_CUBE.sch, power_circuit.sch, pwm_driver.sch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]
2020-05-14 reorganizing repo
    [1x8 SMD Header.0004.ipt, 1x8 SMD Header.ipt, 2019-12-02 CubeBase.ipt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]
2020-05-14 Eclipse FW project plus extras commited
    [2020-05-13 Pin Reference Measurements.xlsx, 476Disco.xlsx, New_configuration.cfg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]
2020-06-04 what happened?
    [476Disco.xlsx, CubeBaseFront.0005.ipt, CubeBase_in.0001.ipt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]
2020-06-09 additional I2C LCD Development
2020-06-15 i2c lcd & mpr121 libary development progress
2020-12-22 initial functional menu system & animations with library reorganization
    [2020-04-28 Motherboard BOM.xlsx]
2021-01-06 committing in case I mess up the code and want to revert to here
    [animations.c]
2021-01-12 FW Dev: added new 'stretchy cube' animation and supporting functions
    [476Disco.xlsx, New_configuration.cfg, l3dcube Debug.cfg]
2021-01-12 general organization
    [2020-04-28 Motherboard BOM.xlsx, 2020-11-03 Pin Mapping.xlsx, CubeBaseFront.0005.ipt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]
2021-01-12 FW Dev: added a couple new randomization functions to be used in 'stretchy cube' animation
2021-02-07 more FW development
    [BOM_TLC5940 Board_2020-04-27_19-26-31.csv]
2026-05-16 2026 Repo cleanup
    [Drill_PTH_Through.DRL, Drill_PTH_Through_Via.DRL, Gerber_BoardOutlineLayer.GKO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]

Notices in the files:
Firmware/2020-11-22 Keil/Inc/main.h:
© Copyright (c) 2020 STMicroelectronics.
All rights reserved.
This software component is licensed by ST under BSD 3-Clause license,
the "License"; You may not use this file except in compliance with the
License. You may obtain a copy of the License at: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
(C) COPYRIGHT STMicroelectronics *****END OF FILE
